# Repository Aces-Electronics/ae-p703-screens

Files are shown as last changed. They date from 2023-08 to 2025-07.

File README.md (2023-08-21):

<h1 align="center">
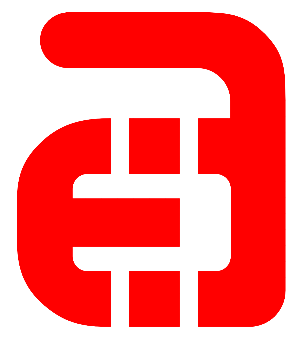
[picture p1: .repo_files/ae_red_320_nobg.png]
Ace's Electronics
    

  Ace's Electronics Pty Ltd  
  Touchscreen IO Control for P703 Rangers  
</h1>

# TOC:
1. <a href="#goals">Goals</a>
1. <a href="#current-states">Current States</a>
   - <a href="#reario-screen">RearIO: Screen</a>
   - <a href="#reario-battery">RearIO: Battery</a>
   - <a href="#reario-screen-and-battery-cradle">RearIO: Screen and Battery Cradle</a>
   - <a href="#reario-basic-pcb">RearIO: Basic PCB</a>
   - <a href="#reario-pro-pcb">RearIO: Pro PCB</a>
   - <a href="#frontio-screen">FrontIO: Screen</a>
1. <a href="#android-app">Android App</a>
1. <a href="#where-to-buy">Where to Buy</a>
1. <a href="#support">Support</a>
---
# Goals:
The goal of this project is to simplify the placement and connection of a secondary battery in a P703 Ranger, by:  
- Creating a touchscreen interface for stats and control, one in the cab and one in the tub  
- Minimise what's required to supply secondary battery power to things like fridges/freezers, lights, fans etc.
- Minimise what's required to turn things on and off  
- Display voltages/currents/power/load states and run flat times etc.
- Create a minimilist version that will require some externall hardware like an MPPT dual input controller etc.

# Current States:
## RearIO Screen
Screen has been sourced and basic prototype code has been written. Seems workable for now but more work is needed.

Screen (WT32-SC01 Plus):  
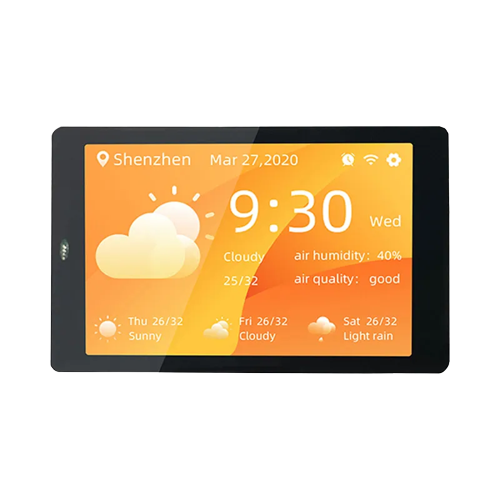
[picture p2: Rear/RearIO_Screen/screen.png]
WT32-SC01 Plus


Buy:
https://core-electronics.com.au/wt32-sc01-plus-esp32-development-board-with-35-inch-lcd-ips-display-touch-screen.html

Datasheet:
https://www.marutsu.co.jp/contents/shop/marutsu/datasheet/khe_WT32-SC01-PLUS.pdf

Basic GUI example: 
It's a WIP, but here's a taste:  
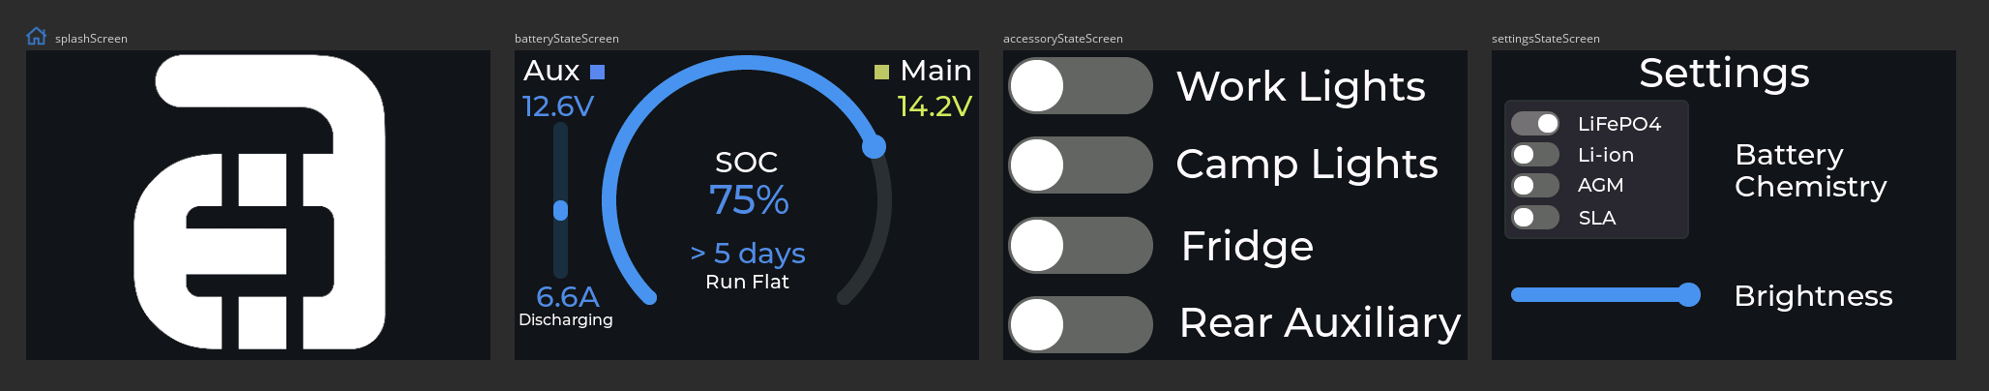
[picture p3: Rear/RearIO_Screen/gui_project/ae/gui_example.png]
GUI Example


## RearIO Battery
50Ah battery has een sourced and tested.  
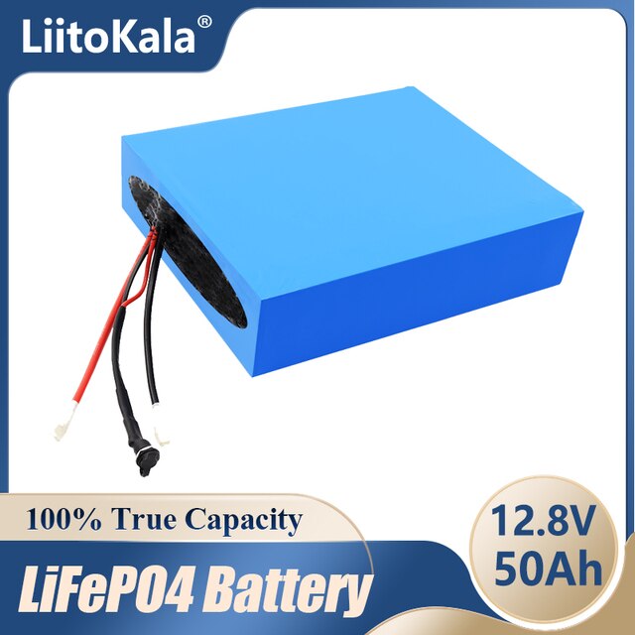
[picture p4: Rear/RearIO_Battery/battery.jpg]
LiFEPO4 Battery


## RearIO Screen and Battery Cradle
The screen and PCB mount is complete. It has cutouts for a marine grade 12v socket + an Anderson socket, and 2 x Anderson sockets.
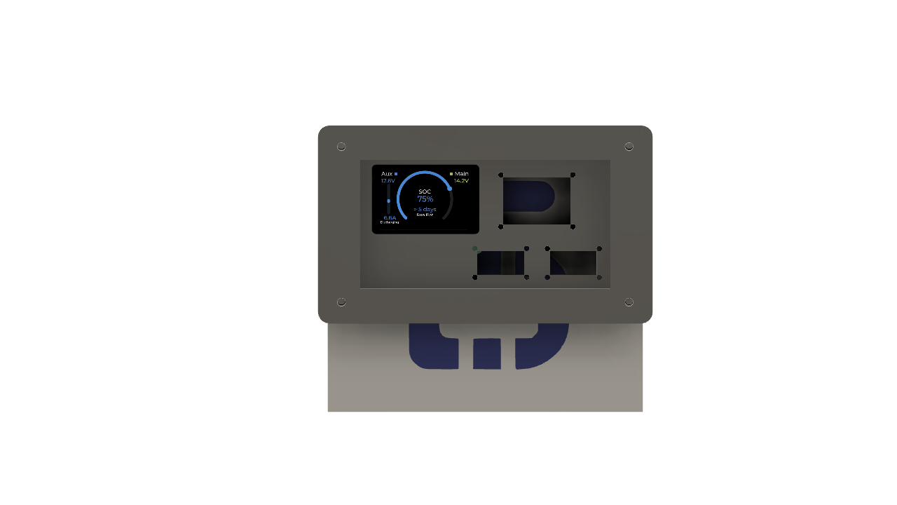
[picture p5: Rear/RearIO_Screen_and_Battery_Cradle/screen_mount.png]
Screen Mount Front

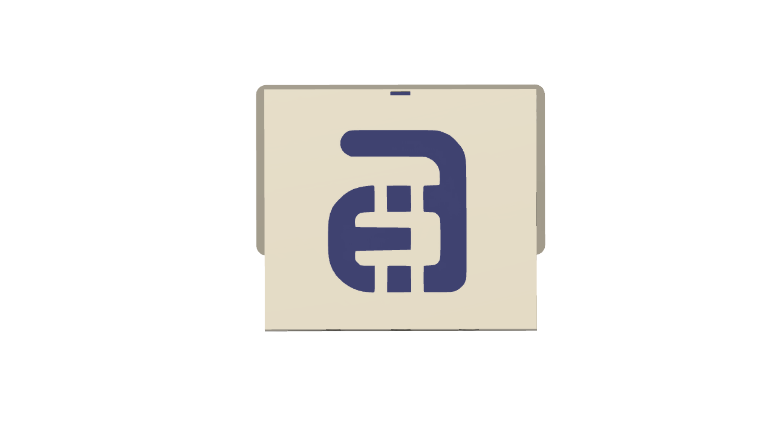
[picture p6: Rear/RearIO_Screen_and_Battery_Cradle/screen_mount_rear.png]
Screen Mount Rear

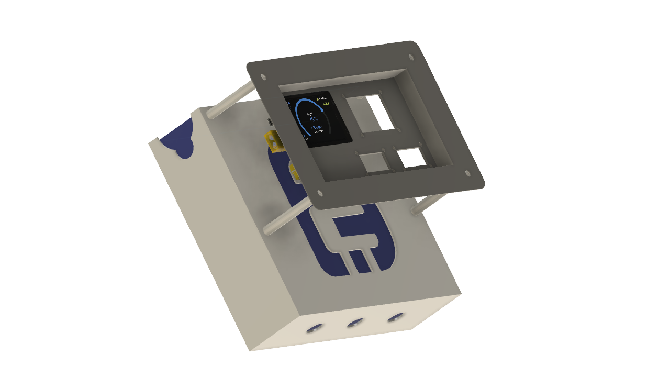
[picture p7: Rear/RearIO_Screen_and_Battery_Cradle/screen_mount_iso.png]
Screen Mount Iso


## RearIO Basic PCB
basic io screenshot The project is currently in the prototyping phase. The PCBs have been sent to JLCPCB and should be here, along with the components, in the next couple of weeks.  
Files: https://github.com/Aces-Electronics/ae-p703-screens/releases/tag/v0.1
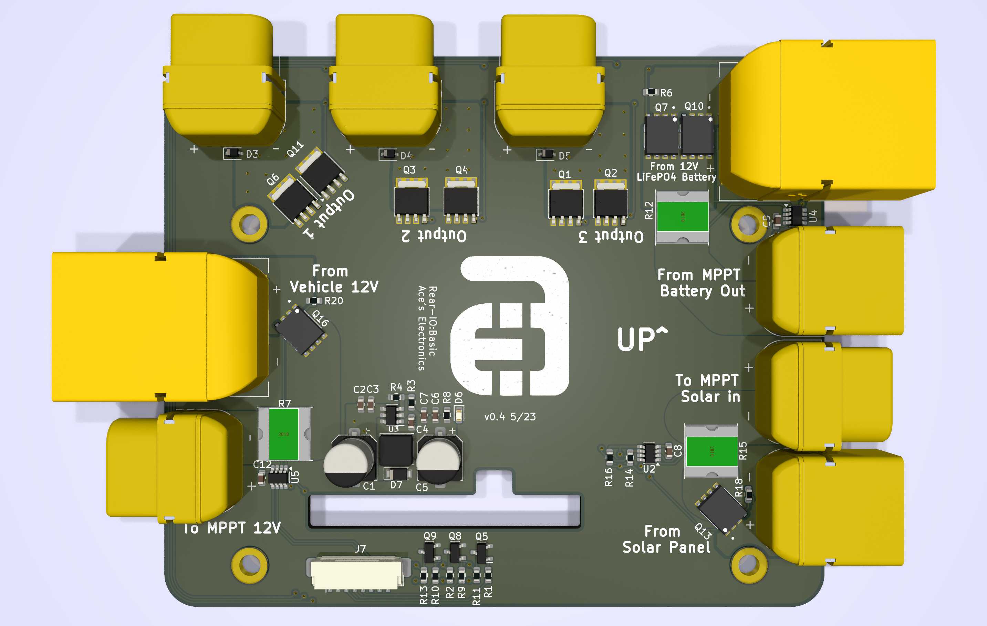
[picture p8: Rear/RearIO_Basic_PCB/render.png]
Basic PCB

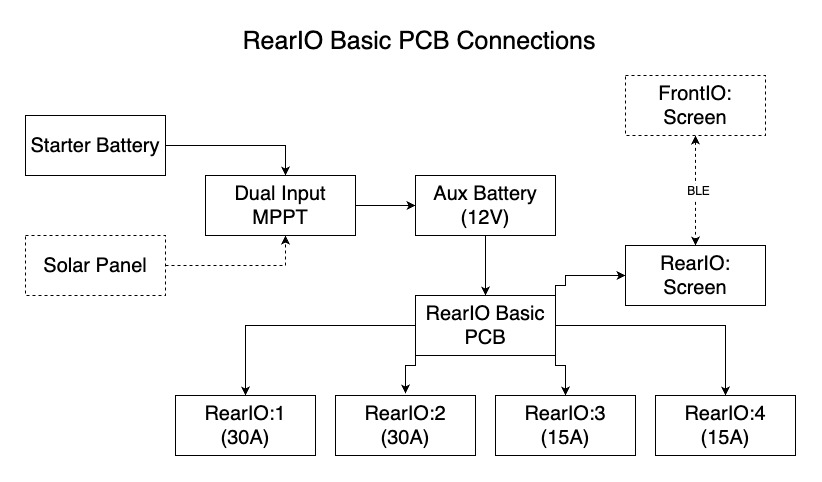
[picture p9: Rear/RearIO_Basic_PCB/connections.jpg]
Basic PCB Connections


## RearIO Pro PCB
The project is in the design stage, and is coming along as time allows.
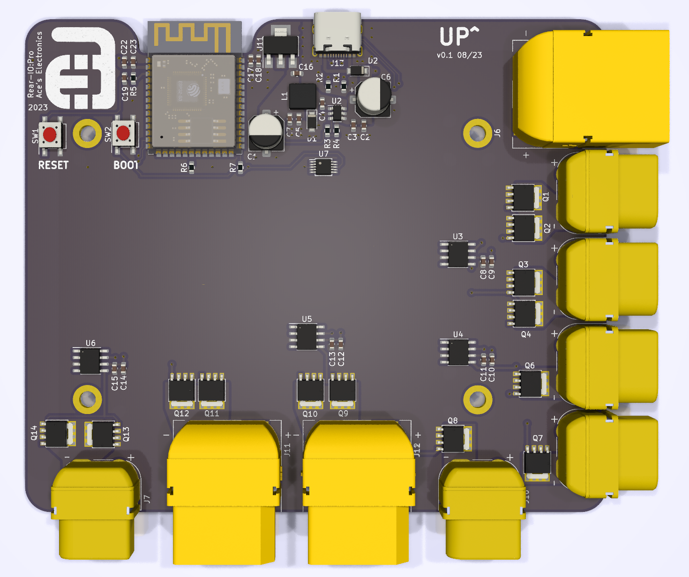
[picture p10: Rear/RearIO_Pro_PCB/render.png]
Pro PCB


## FrontIO Screen
Screen has been sourced. No testing has been done yet.
https://www.makerfabs.com/matouch-esp32-s3-parallel-tft-with-touch-1-9-inch.html  
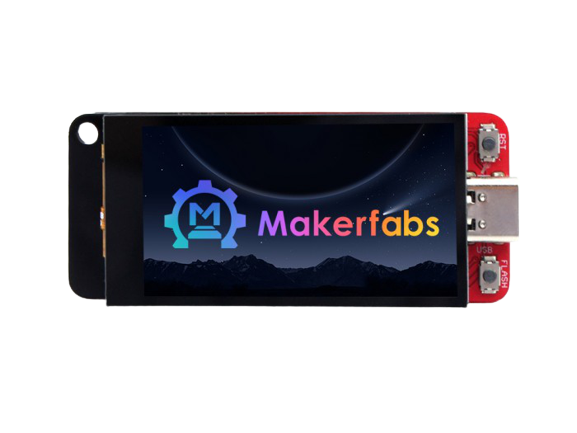
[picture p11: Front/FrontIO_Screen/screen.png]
MaTouch_ESP32-S3 Parallel TFT with Touch 1.9" ST7789V2


## Android App
Not yet started

# Where to Buy:
TBA

## Support:
Contact me direct via ace<@>aceselectronics.com.au, just make it look like a normal email address. (hiding from the bots ;) )

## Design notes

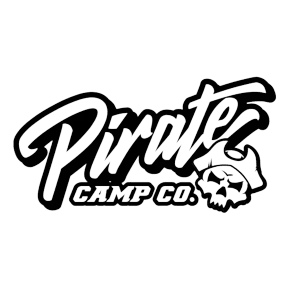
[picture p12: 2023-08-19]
Rear/RearIO_Screen_Basic_Software/gui_project/pcc/assets/pirate_camp_co_290.png

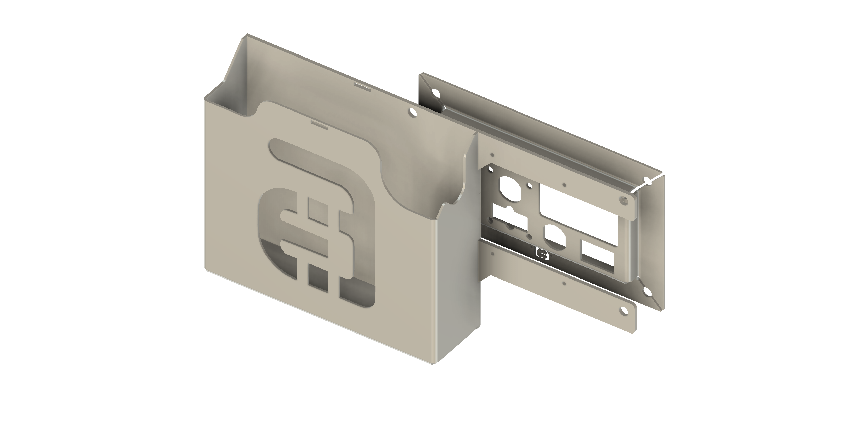
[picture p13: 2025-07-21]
Panel v64.png

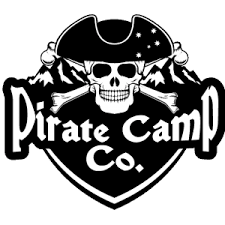
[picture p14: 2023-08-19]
Rear/RearIO_Screen_Pro_Software/gui_project/pcc/assets/images.png

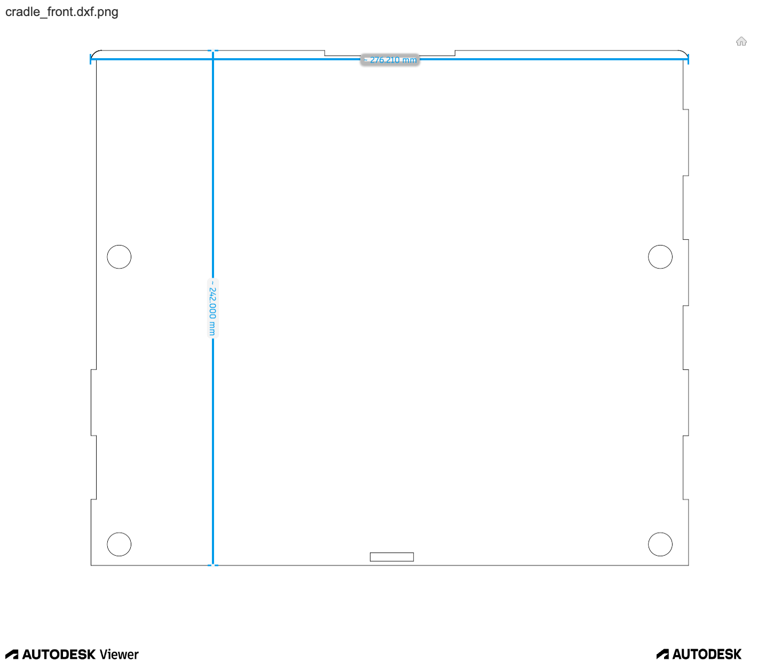
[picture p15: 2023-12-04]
Rear/RearIO_Screen_and_Battery_Cradle/DXF/folding/cradle_front.dxf.png

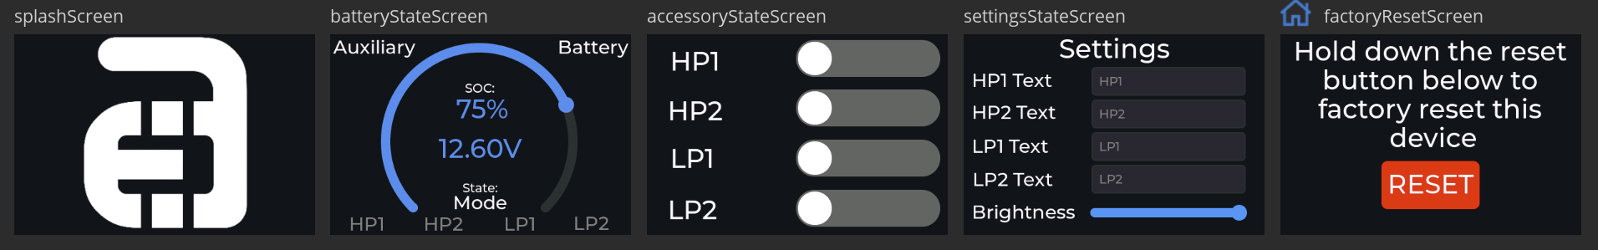
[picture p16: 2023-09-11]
Rear/RearIO_Screen_Pro_Software/gui_project/ae/gui_example.png

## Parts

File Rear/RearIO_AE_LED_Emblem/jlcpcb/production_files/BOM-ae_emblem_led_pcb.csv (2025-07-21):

Comment | Designator | Footprint | LCSC
330R | R1,R2,R3,R4,R5,R6 | R_0402_1005Metric | C12246
Conn_01x02_Socket | J1 | Hirose_DF13C_CL535-0402-2-51_1x02-1MP_P1.25mm_Vertical | C3029359
GREEN_LED | D1,D2,D3,D4,D5,D6 | LED_0402_1005Metric | C434449

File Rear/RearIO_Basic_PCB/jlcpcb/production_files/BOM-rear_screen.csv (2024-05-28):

Comment | Designator | Footprint | LCSC
82k | R3 | R_0603_1608Metric | C103831
1k | R1,R10,R9 | R_0603_1608Metric | C21190
2k | R14,R16 | R_0603_1608Metric | C22975
5.1k | R8 | R_0603_1608Metric | C23186
10uH | L1 | L_Chilisin_BMRA00040415 | C2847473
1N5819WS | D3,D4,D5 | D_SOD-323 | C2927280
Conn_01x02_Pin | J10,J6 | AMASS_XT90PW-M | C3040689
100nF | C12,C2,C3,C4,C6,C7,C8,C9 | C_0603_1608Metric | C30926
220uF | C1 | CP_Elec_6.3x7.7 | C340768
AON6411 | Q10,Q13,Q16,Q7 | PowerDI5060-8 | C397981
16k | R11,R13,R18,R2,R20,R4,R6 | R_0603_1608Metric | C4210
Conn_01x02_Pin | J1,J11,J3,J4,J5 | AMASS_XT60PW-F_1x02_P7.20mm_Horizontal | C428722
10mR | R12,R15,R7 | 2728R_C500749 | C500749
AOZ1280CI | U3 | SOT-23-6 | C5123971
NTMFS4C03N-HXY | Q1,Q11,Q2,Q3,Q4,Q6 | LFPAK56 | C5148663
Conn_01x08_Socket | J7 | BOOMELE-Boom-Precision-Elec-C53040_C53040 | C53040
INA236AIDDFR_C5443912 | U2,U4,U5 | SOT-23-8 | C5443912
LED_Small | D6 | LED_0603_1608Metric | C84264
MMBT3904 | Q5,Q8,Q9 | SOT-23 | C8512
PMEG6020ER | D7 | Nexperia_CFP3_SOD-123W | C98663
Conn_01x02_Pin | J2,J9 | AMASS_XT60PW-M_1x02_P7.20mm_Horizontal | C98732
22uF | C5 | CP_Elec_6.3x5.4 | C98744

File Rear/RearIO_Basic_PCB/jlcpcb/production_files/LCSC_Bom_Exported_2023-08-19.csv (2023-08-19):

LCSC Part Number | Quoted Manufacturer | Quoted LCSC Part Number | Quoted Manufacturer Part Number | Quantity | Unit Price | Order Price | Quantity Available | Min\Mult Order Qty | RoHS | Part Match Confidence
C103831 | RALEC | C103831 | RTT038202FTP | 100 | 0.0028 | 0.28 | 99700 | 100\100 | yes | 100%
C23186 | UNI-ROYAL(Uniroyal Elec) | C23186 | 0603WAF5101T5E | 100 | 0.001 | 0.10 | 1548200 | 100\100 | yes | 100%
C2685358 | COSINE | C2685358 | COS4427SR | 10 | 0.3882 | 3.88 | 20107 | 1\1 | yes | 100%
C2847473 | KOHERelec | C2847473 | MDA4020-100M | 5 | 0.7701 | 3.85 | 2076 | 1\1 | yes | 100%
C2927280 | JSMSEMI | C2927280 | 1N5819WS S4 | 25 | 0.0085 | 0.20 | 558490 | 5\5 | yes | 100%
C2988369 | G-Switch | C2988369 | GT-USB-7010ASV | 5 | 0.0787 | 0.35 | 39365 | 5\5 | yes | 100%
C3040689 | Changzhou Amass Elec | C3040689 | XT90PW-M.G.Y | 5 | 0.63 | 3.02 | 725 | 1\1 | yes | 100%
C30926 | FH (Guangdong Fenghua Advanced Tech) | C30926 | 0603B104K500NT | 100 | 0.0023 | 0.23 | 40547100 | 100\100 | yes | 100%
C4210 | UNI-ROYAL(Uniroyal Elec) | C4210 | 0603WAF1602T5E | 100 | 0.001 | 0.10 | 322600 | 100\100 | yes | 100%
C5123971 | Legend-Si | C5123971 | LGS5145 | 5 | 0.1169 | 0.50 | 51050 | 5\5 | yes | 100%
C5148663 | HXY MOSFET | C5148663 | NTMFS4C03N-HXY | 30 | 0.2801 | 8.40 | 469 | 1\1 | yes | 100%
C53040 | BOOMELE(Boom Precision Elec) | C53040 | C53040 | 19 | 0.0781 | 1.48 | 6650 | 19\19 | yes | 100%
C98663 | Nexperia | C98663 | PMEG6020ER,115 | 5 | 0.1329 | 0.66 | 10075 | 5\5 | yes | 100%
C98744 | ST(Semtech) | C98744 | CS1H220M-CRE54 | 10 | 0.0274 | 0.27 | 103030 | 10\10 | yes | 100%
C99836 | ROQANG | C99836 | RVE1C221M0607 | 10 | 0.0446 | 0.40 | 310710 | 10\10 | yes | 100%

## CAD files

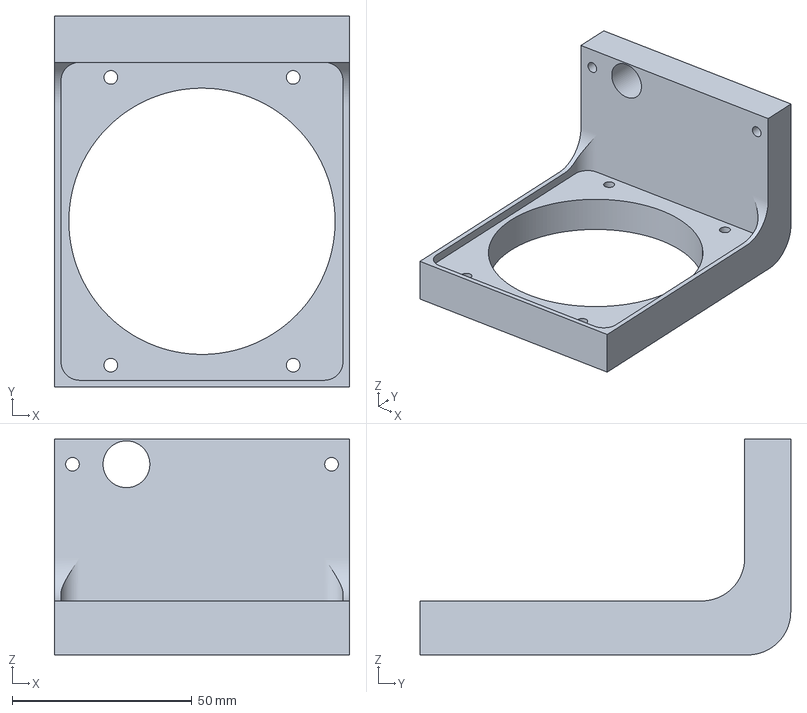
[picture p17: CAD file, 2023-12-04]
Engine_Bay/battery_isolator_bracket.3mf
82.0 x 103.0 x 60.0 mm

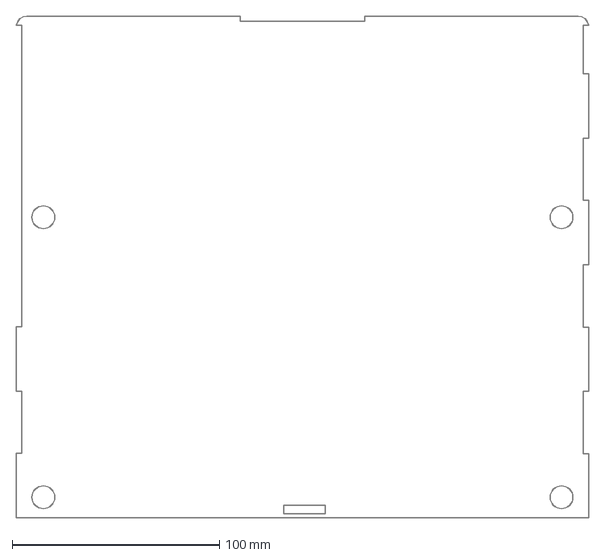
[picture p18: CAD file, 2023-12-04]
Rear/RearIO_Screen_and_Battery_Cradle/DXF/folding/cradle_front.dxf
276.0 x 242.0 mm

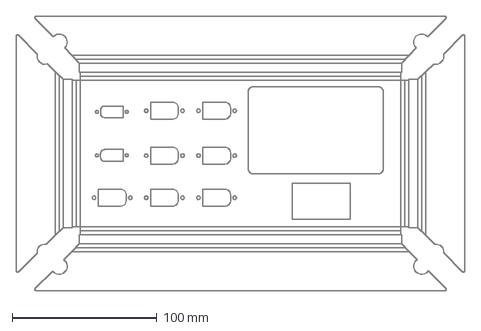
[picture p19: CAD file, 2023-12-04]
Rear/RearIO_Screen_and_Battery_Cradle/DXF/folding/panel.dxf
309.6 x 189.6 mm

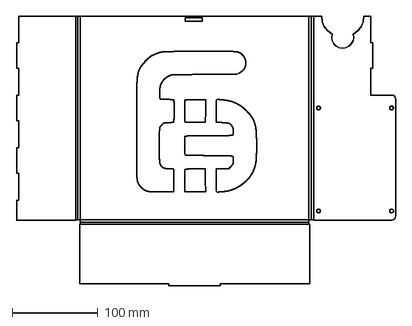
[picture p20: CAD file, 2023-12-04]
Rear/RearIO_Screen_and_Battery_Cradle/DXF/folding/cradle_rear.dxf
441.9 x 314.3 mm

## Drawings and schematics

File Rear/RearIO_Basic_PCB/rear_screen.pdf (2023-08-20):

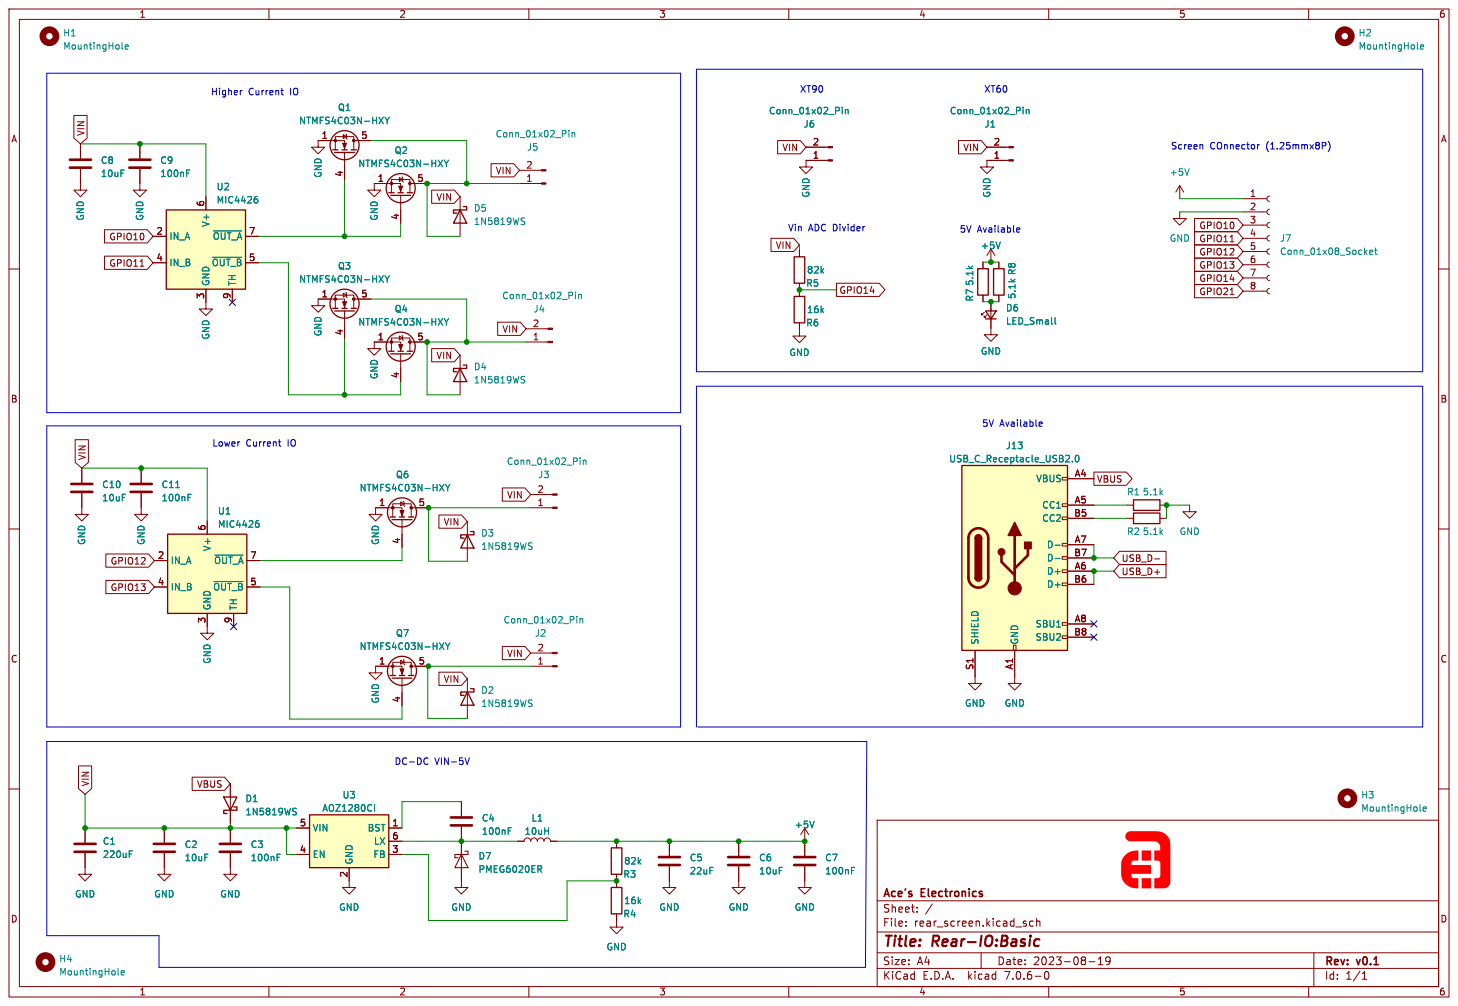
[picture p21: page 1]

6 ~{OUT_A}7 U2 MIC4426 GND GND GND GND

Id: 1/1 Title: Rear-IO:Basic

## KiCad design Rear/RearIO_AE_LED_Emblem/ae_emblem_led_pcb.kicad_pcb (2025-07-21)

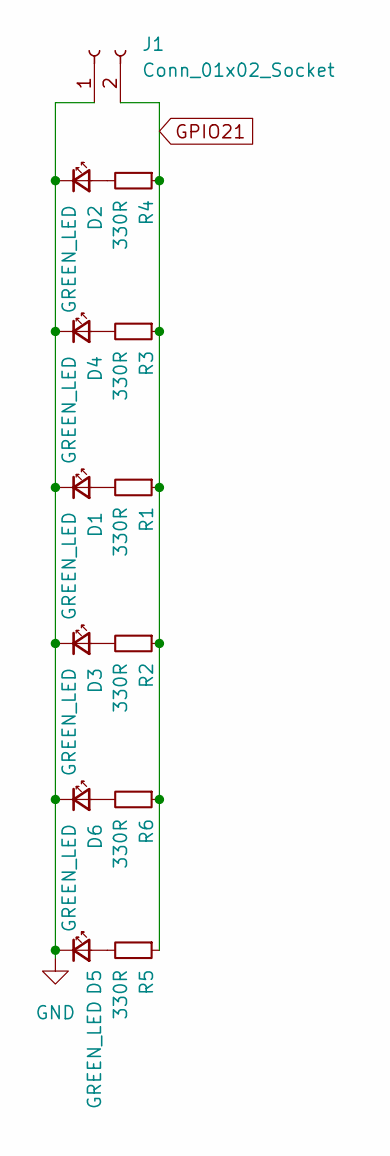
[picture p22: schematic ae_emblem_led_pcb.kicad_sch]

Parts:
D1, D2, D3, D4, D5, D6: GREEN_LED; LED_0402_1005Metric; lcsc C434449
J1: Conn_01x02_Socket; Hirose_DF13C_CL535-0402-2-51_1x02-1MP_P1.25mm_Vertical; lcsc C3029359
R1, R2, R3, R4, R5, R6: 330R; R_0402_1005Metric; lcsc C12246

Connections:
GND: D1.1 (K), D2.1 (K), D3.1 (K), D4.1 (K), D5.1 (K), D6.1 (K), J1.1
GPIO21: J1.2, R1.1, R2.1, R3.1, R4.1, R5.1, R6.1
unnamed: D1.2 (A), R1.2
unnamed: D2.2 (A), R4.2
unnamed: D3.2 (A), R2.2
unnamed: D4.2 (A), R3.2
unnamed: D5.2 (A), R5.2
unnamed: D6.2 (A), R6.2

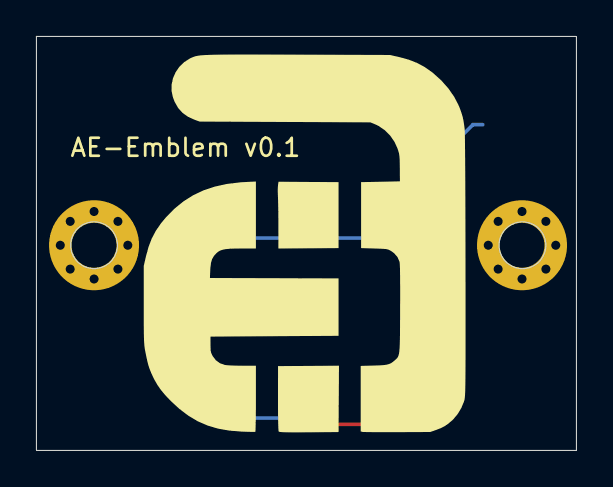
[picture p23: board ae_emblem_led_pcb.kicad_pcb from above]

Board: 2 copper layers, 30.0 x 23.0 mm, 13 parts (1 on the bottom side), 8 nets.

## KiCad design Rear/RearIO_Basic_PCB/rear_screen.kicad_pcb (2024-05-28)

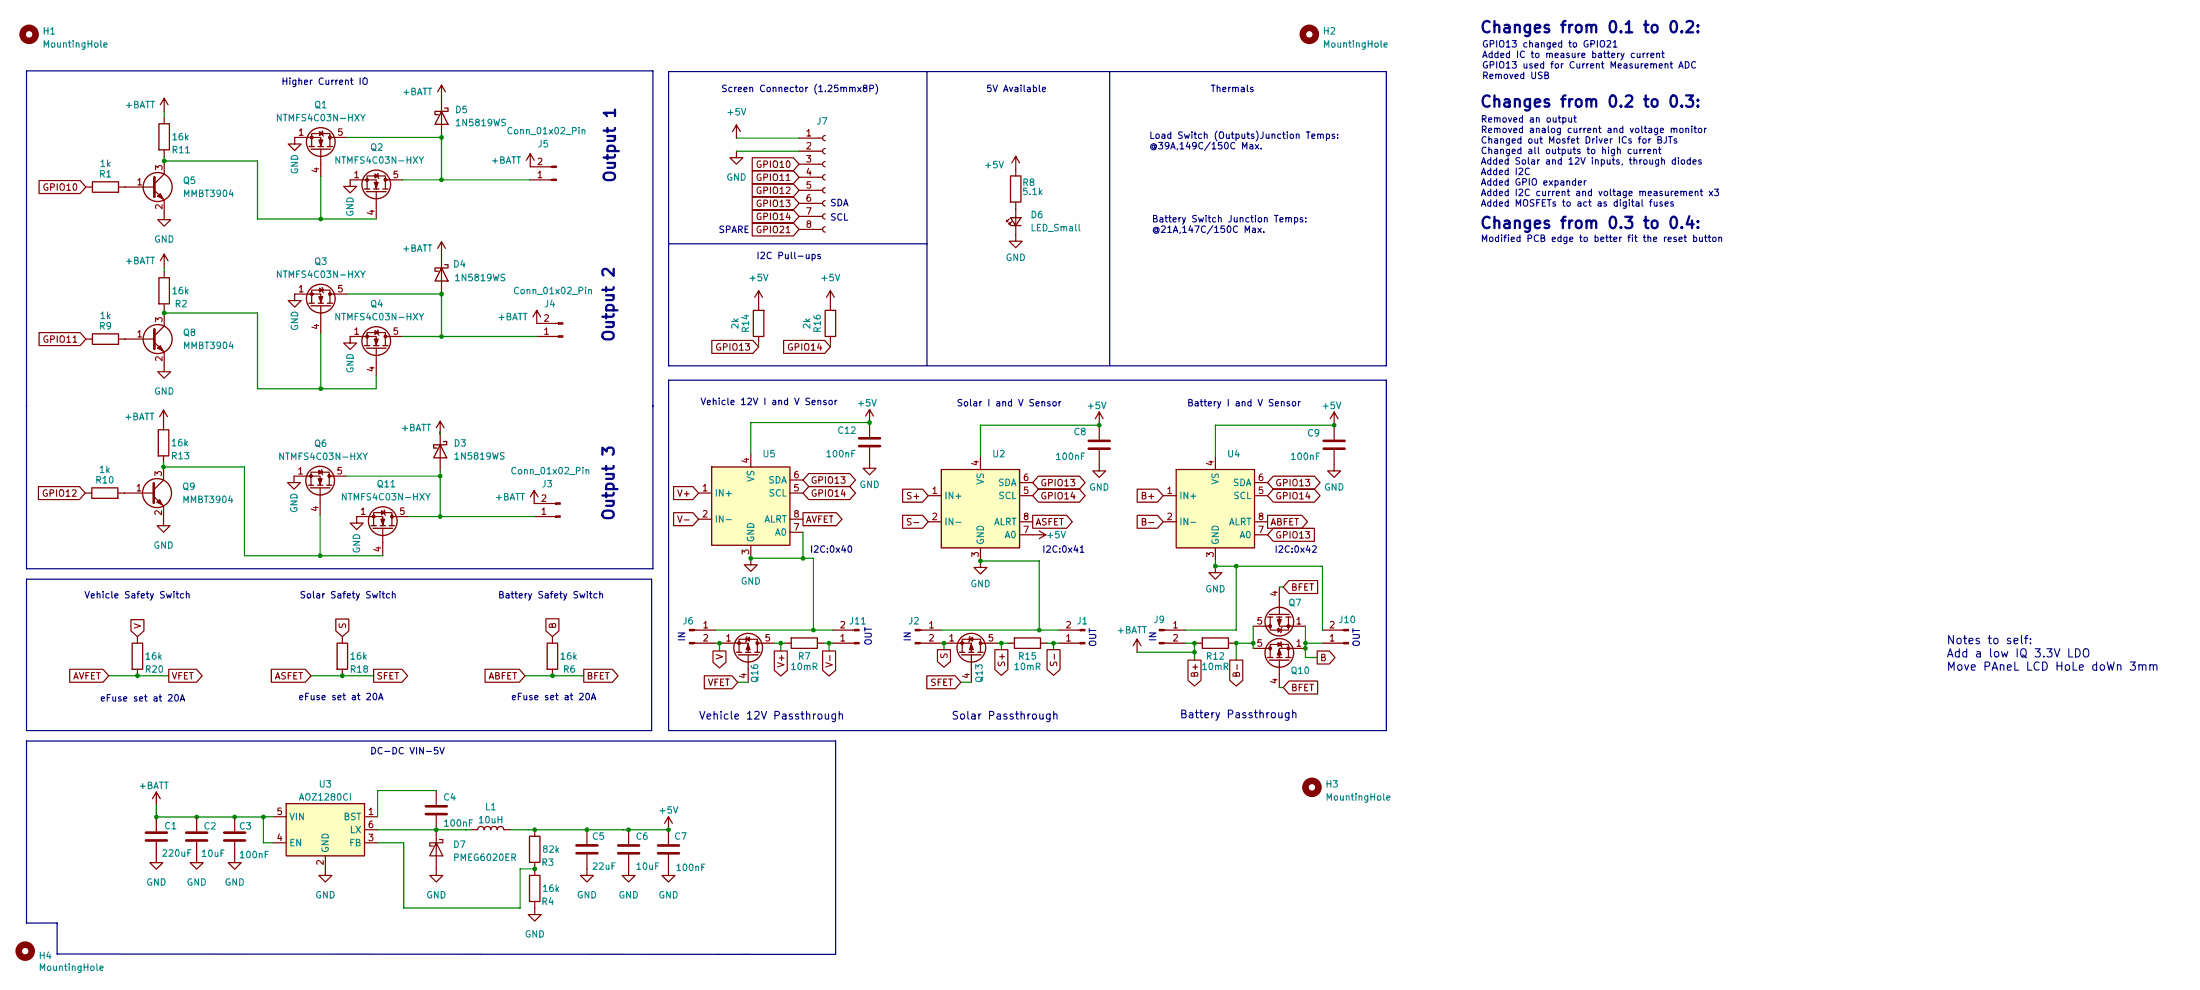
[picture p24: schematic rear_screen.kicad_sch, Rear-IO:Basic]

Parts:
C1: 220uF; CP_Elec_6.3x7.7; lcsc C340768
C2, C6: 10uF; C_0603_1608Metric; lcsc C30926
C3, C4, C7, C8, C9, C12: 100nF; C_0603_1608Metric; lcsc C30926
C5: 22uF; CP_Elec_6.3x5.4; lcsc C98744
D3, D4, D5: 1N5819WS; D_SOD-323; lcsc C2927280
D6: LED_Small; LED_0603_1608Metric; lcsc C84264
D7: PMEG6020ER; Nexperia_CFP3_SOD-123W; lcsc C98663
H1, H2, H3, H4: MountingHole; MountingHole_3.2mm_M3_DIN965_Pad
J1, J3, J4, J5, J11: Conn_01x02_Pin; AMASS_XT60PW-F_1x02_P7.20mm_Horizontal; lcsc C428722
J2, J9: Conn_01x02_Pin; AMASS_XT60PW-M_1x02_P7.20mm_Horizontal; lcsc C98732
J6, J10: Conn_01x02_Pin; AMASS_XT90PW-M; lcsc C3040689
J7: Conn_01x08_Socket; BOOMELE-Boom-Precision-Elec-C53040_C53040; lcsc C53040
L1: 10uH; L_Chilisin_BMRA00040415; lcsc C2847473
Q1, Q2, Q3, Q4, Q6, Q11: NTMFS4C03N-HXY; LFPAK56; lcsc C5148663
Q5, Q8, Q9: MMBT3904; SOT-23; lcsc C8512
Q7, Q10, Q13, Q16: AON6411; PowerDI5060-8; lcsc C397981
R1, R9, R10: 1k; R_0603_1608Metric; lcsc C21190
R2, R4, R6, R11, R13, R18, R20: 16k; R_0603_1608Metric; lcsc C4210
R3: 82k; R_0603_1608Metric; lcsc C103831
R7, R12, R15: 10mR; 2728R_C500749; lcsc C500749
R8: 5.1k; R_0603_1608Metric; lcsc C23186
R14, R16: 2k; R_0603_1608Metric; lcsc C22975
U2, U4, U5: INA236AIDDFR_C5443912; SOT-23-8; lcsc C5443912
U3: AOZ1280CI; SOT-23-6; lcsc C5123971

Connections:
+5V: C5.1, C6.1, C7.1, C8.1, C9.1, C12.1, J7.1, L1.2, R3.1, R8.1, R14.2, R16.2, U2.4 (VS), U2.7 (A0), U4.4 (VS), U5.4 (VS)
ABFET: Q7.4 (G), Q10.4 (G), R6.2, U4.8 (ALRT)
ASFET: Q13.4 (G), R18.2, U2.8 (ALRT)
AVFET: Q16.4 (G), R20.2, U5.8 (ALRT)
B: J10.1, Q7.1 (S), Q7.2 (S), Q7.3 (S), Q10.1 (S), Q10.2 (S), Q10.3 (S), R6.1
B+: C1.1, C2.1, C3.1, D3.1 (K), D4.1 (K), D5.1 (K), J3.2, J4.2, J5.2, J9.2, R2.1, R11.1, R12.2, R13.1, U3.4 (EN), U3.5 (VIN), U4.1 (IN+)
B-: Q7.5 (D), Q10.5 (D), R12.1, U4.2 (IN-)
GND: C1.2, C2.2, C3.2, C5.2, C6.2, C7.2, C8.2, C9.2, C12.2, D6.1 (K), D7.2 (A), J1.2, J2.1, J6.1, J7.2, J9.1, J10.2, J11.2, Q1.1 (S), Q1.2 (S), Q1.3 (S), Q2.1 (S), Q2.2 (S), Q2.3 (S), Q3.1 (S), Q3.2 (S), Q3.3 (S), Q4.1 (S), Q4.2 (S), Q4.3 (S), Q5.2 (E), Q6.1 (S), Q6.2 (S), Q6.3 (S), Q8.2 (E), Q9.2 (E), Q11.1 (S), Q11.2 (S), Q11.3 (S), R4.2, U2.3 (GND), U3.2 (GND), U4.3 (GND), U5.3 (GND), U5.7 (A0)
GPIO10: J7.3, R1.1
GPIO11: J7.4, R9.1
GPIO12: J7.5, R10.1
GPIO13: J7.6, R14.1, U2.6 (SDA), U4.6 (SDA), U4.7 (A0), U5.6 (SDA)
GPIO14: J7.7, R16.1, U2.5 (SCL), U4.5 (SCL), U5.5 (SCL)
GPIO21: J7.8
unnamed: D3.2 (A), J3.1, Q6.5 (D), Q11.5 (D)
unnamed: D4.2 (A), J4.1, Q3.5 (D), Q4.5 (D)
unnamed: D5.2 (A), J5.1, Q1.5 (D), Q2.5 (D)
unnamed: D6.2 (A), R8.2
unnamed: C4.2, D7.1 (K), L1.1, U3.6 (LX)
unnamed: Q1.4 (G), Q2.4 (G), Q5.3 (C), R11.2
unnamed: Q3.4 (G), Q4.4 (G), Q8.3 (C), R2.2
unnamed: Q5.1 (B), R1.2
unnamed: Q8.1 (B), R9.2
unnamed: Q9.1 (B), R10.2
unnamed: Q6.4 (G), Q9.3 (C), Q11.4 (G), R13.2
unnamed: C4.1, U3.1 (BST)
unnamed: R3.2, R4.1, U3.3 (FB)
S: J2.2, Q13.1 (S), Q13.2 (S), Q13.3 (S), R18.1
S+: Q13.5 (D), R15.2, U2.1 (IN+)
S-: J1.1, R15.1, U2.2 (IN-)
V: J6.2, Q16.1 (S), Q16.2 (S), Q16.3 (S), R20.1
V+: Q16.5 (D), R7.2, U5.1 (IN+)
V-: J11.1, R7.1, U5.2 (IN-)

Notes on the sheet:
Higher Current IO
I2C:0x40
Changes from 0.3 to 0.4:
Changes from 0.2 to 0.3:
Vehicle Safety Switch
I2C:0x41
Battery Passthrough
Load Switch (Outputs)Junction Temps: @39A,149C/150C Max.
OUT
eFuse set at 20A
Output 2
Battery Switch Junction Temps: @21A,147C/150C Max.
DC-DC VIN-5V
Output 1
Vehicle 12V Passthrough
Screen Connector (1.25mmx8P)
Vehicle 12V I and V Sensor
Output 3
Solar Safety Switch
Changes from 0.1 to 0.2:
I2C:0x42
Battery I and V Sensor
Solar I and V Sensor
Battery Safety Switch
Removed an output Removed analog current and voltage monitor Changed out Mosfet Driver ICs for BJTs Changed all outputs to high current Added Solar and 12V inputs, through diodes Added I2C Added GPIO expander Added I2C current and voltage measurement x3 Added MOSFETs to act as digital fuses
I2C Pull-ups
Modified PCB edge to better fit the reset button
SDA
Thermals
SPARE
5V Available
Notes to self: Add a low IQ 3.3V LDO Move PAneL LCD HoLe doWn 3mm
Solar Passthrough
SCL
GPIO13 changed to GPIO21 Added IC to measure battery current GPIO13 used for Current Measurement ADC Removed USB

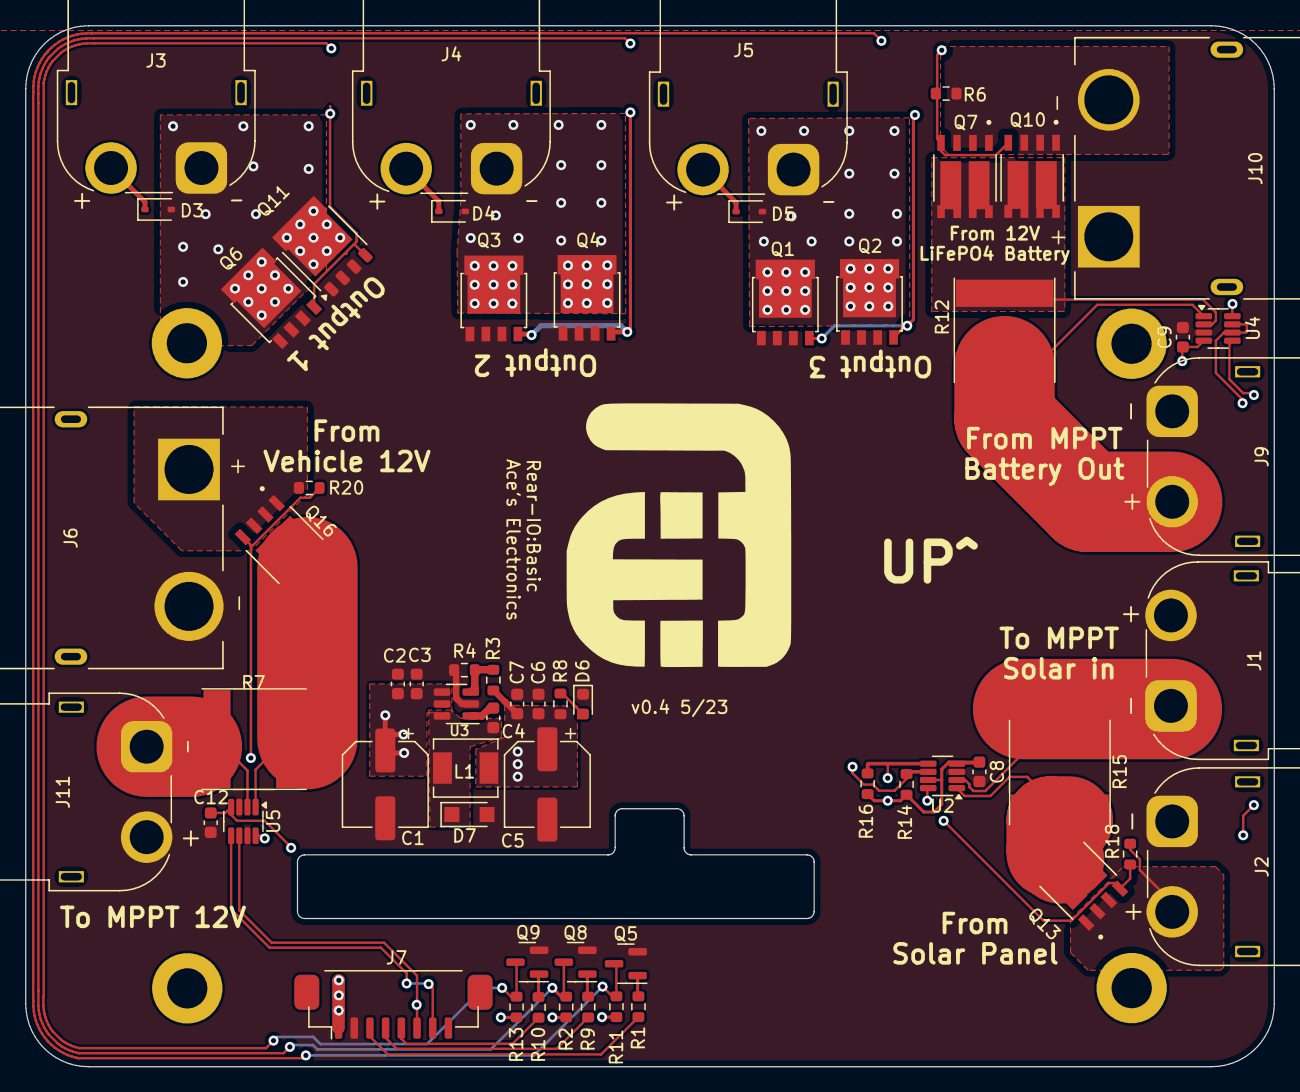
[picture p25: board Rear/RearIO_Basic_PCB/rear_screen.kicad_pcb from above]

Board: 4 copper layers, 99.4 x 82.9 mm, 64 parts (0 on the bottom side), 32 nets.

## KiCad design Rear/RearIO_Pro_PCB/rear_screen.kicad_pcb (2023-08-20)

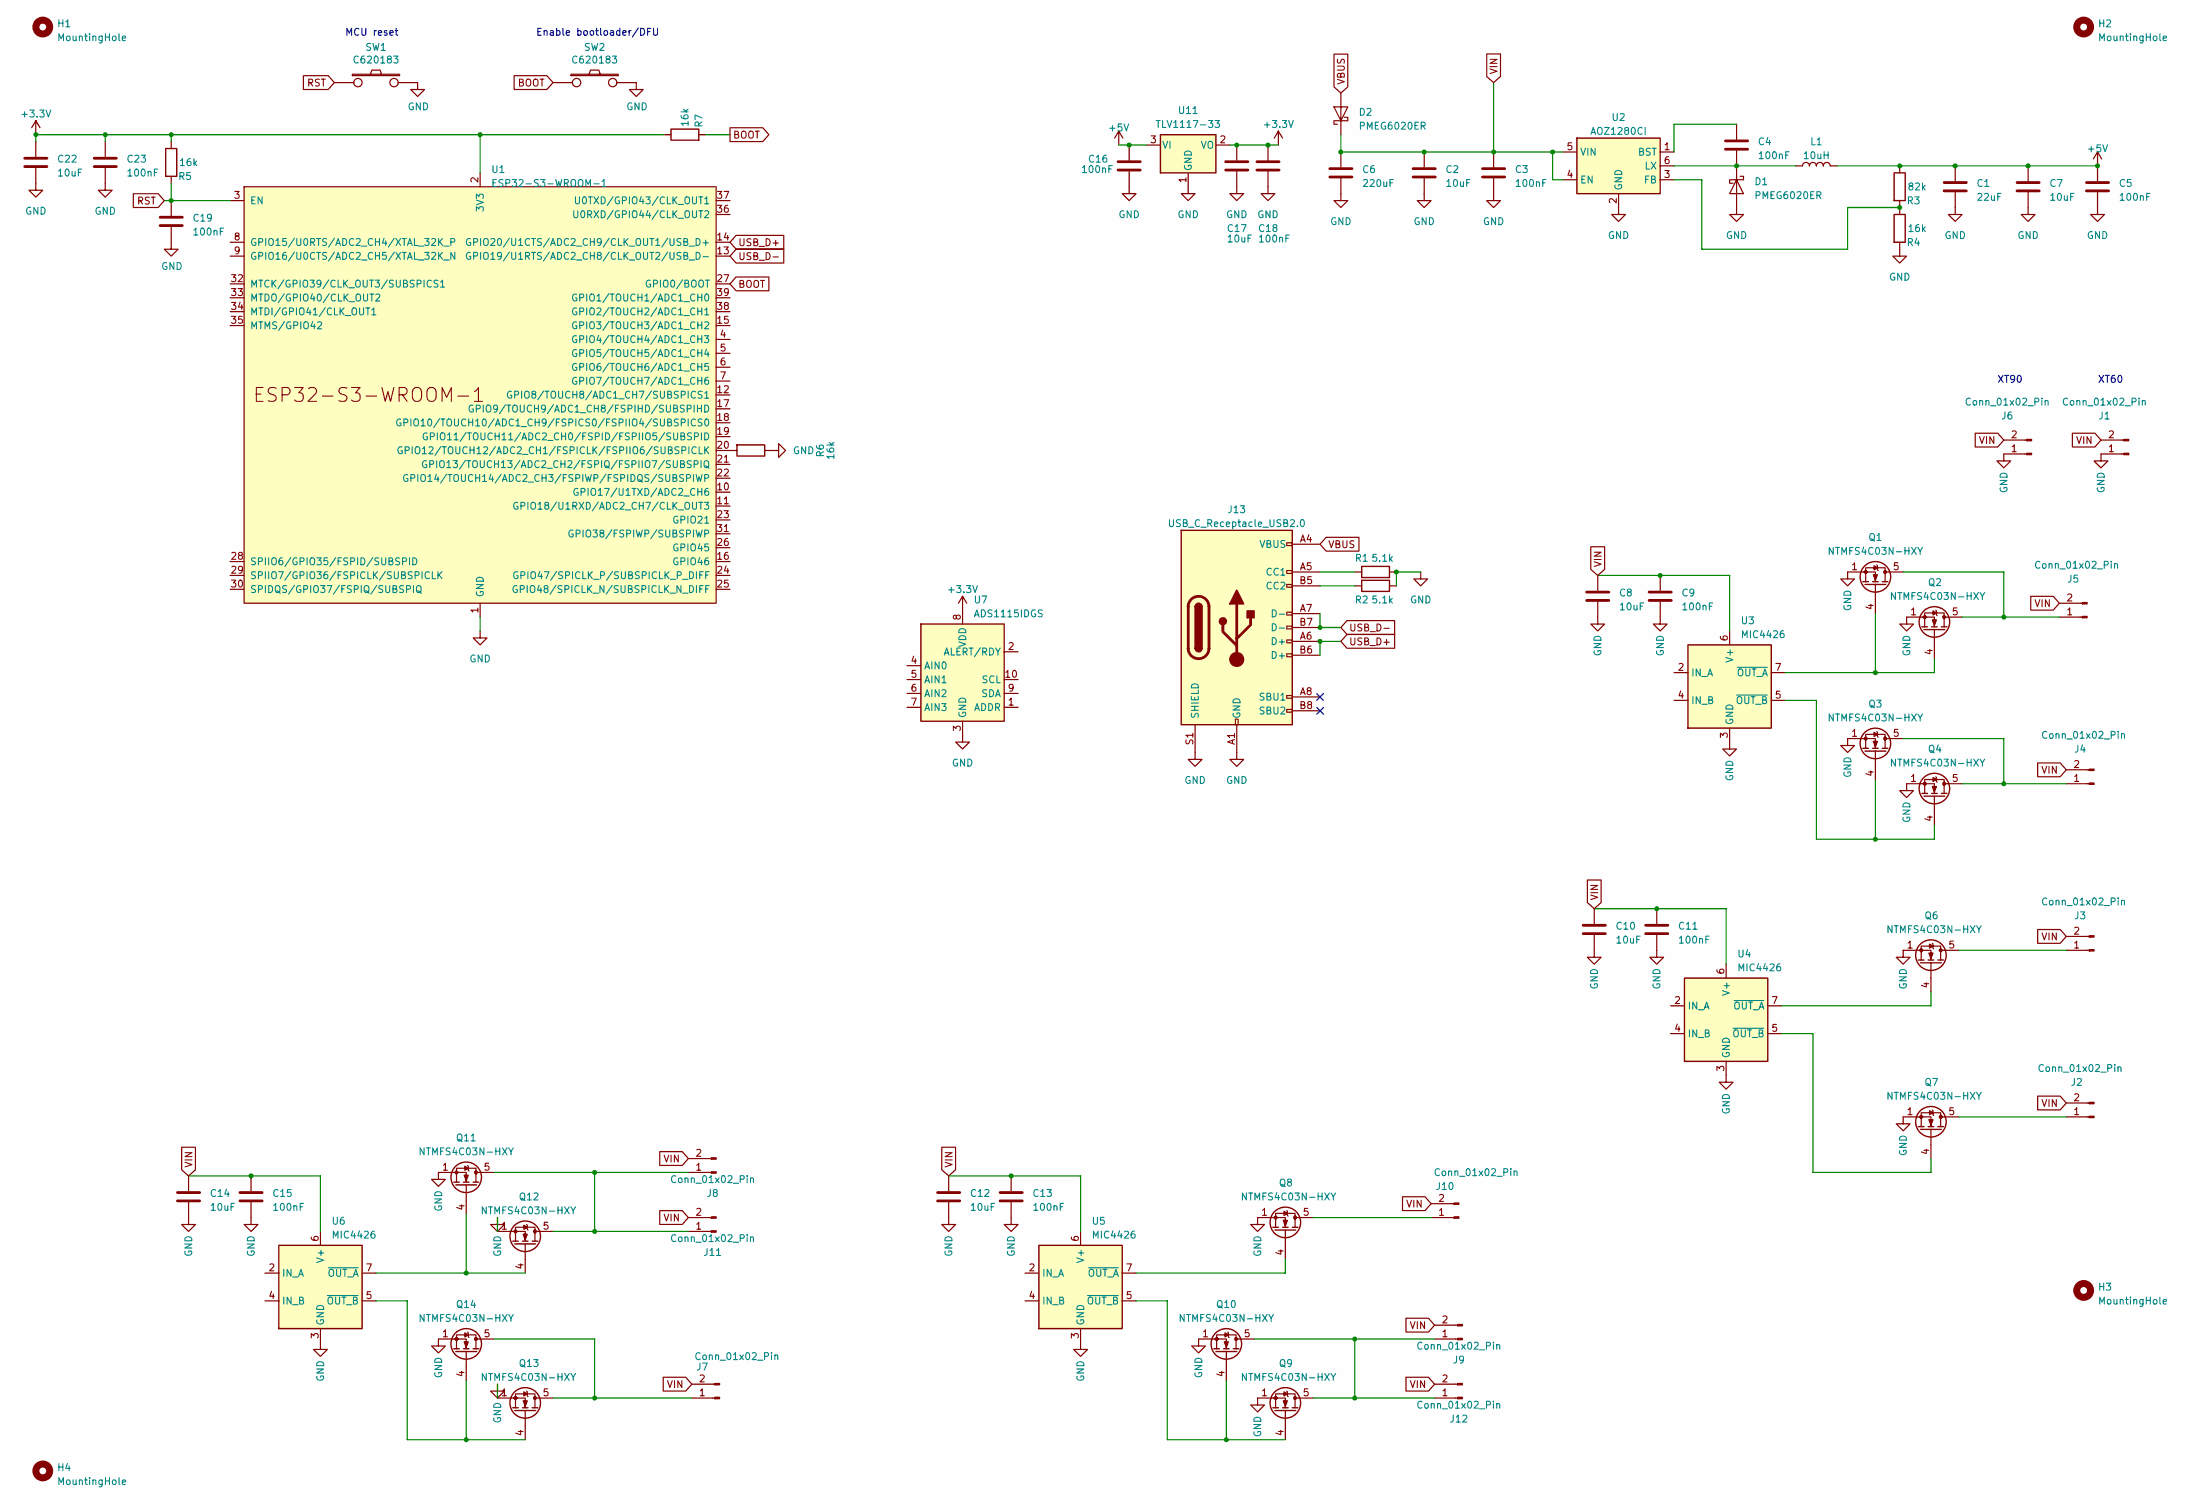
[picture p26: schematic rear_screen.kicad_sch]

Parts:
C1: 22uF; CP_Elec_6.3x5.4; lcsc C98744
C2, C7, C8, C10, C12, C14, C17, C22: 10uF; C_0603_1608Metric; lcsc C30926
C3, C4, C5, C9, C11, C13, C15, C16, C18, C19, C23: 100nF; C_0603_1608Metric; lcsc C30926
C6: 220uF; CP_Elec_6.3x7.7; lcsc C99836
D1, D2: PMEG6020ER; Nexperia_CFP3_SOD-123W; lcsc C98663
H1, H2, H3, H4: MountingHole; MountingHole_3.2mm_M3_DIN965_Pad
J1: Conn_01x02_Pin; AMASS_XT60PW-M_1x02_P7.20mm_Horizontal; lcsc C98732
J2, J3, J4, J5, J7, J8, J9, J10: Conn_01x02_Pin; AMASS_XT60PW-F_1x02_P7.20mm_Horizontal; lcsc C428722
J6: Conn_01x02_Pin; AMASS_XT90PW-M; lcsc C3040689
J11, J12: Conn_01x02_Pin; AMASS_XT90PW-F; lcsc C3040690
J13: USB_C_Receptacle_USB2.0; USB_C_Receptacle_G-Switch_GT-USB-7010ASV; lcsc C2988369
L1: 10uH; L_Chilisin_BMRA00040415; lcsc C2847473
Q1, Q2, Q3, Q4, Q6, Q7, Q8, Q9, Q10, Q11, Q12, Q13, Q14: NTMFS4C03N-HXY; LFPAK56; lcsc C5148663
R1, R2: 5.1k; R_0603_1608Metric; lcsc C23186
R3: 82k; R_0603_1608Metric; lcsc C103831
R4, R5, R6, R7: 16k; R_0603_1608Metric; lcsc C4210
SW1: C620183; TS4550TP; lcsc C620183
SW2: C620183; TS4550TP; lcsc_part_number C620183
U1: ESP32-S3-WROOM-1
U2: AOZ1280CI; SOT-23-6; lcsc C5123971
U3, U4, U5, U6: MIC4426; HSOP-8-1EP_3.9x4.9mm_P1.27mm_EP2.41x3.1mm_ThermalVias; lcsc C2685358
U7: ADS1115IDGS; TSSOP-10_3x3mm_P0.5mm
U11: TLV1117-33; SOT-223; lcsc C15578

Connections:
+3.3V: C17.1, C18.1, C22.1, C23.1, R5.1, R7.1, U1.2 (3V3), U7.8 (VDD), U11.2 (VO)
+5V: C1.1, C5.1, C7.1, C16.1, L1.2, R3.1, U11.3 (VI)
BOOT: R7.2, SW2.1, U1.27 (GPIO0/BOOT)
GND: C1.2, C2.2, C3.2, C5.2, C6.2, C7.2, C8.2, C9.2, C10.2, C11.2, C12.2, C13.2, C14.2, C15.2, C16.2, C17.2, C18.2, C19.2, C22.2, C23.2, D1.2 (A), J1.1, J6.1, J13.A1 (GND), J13.A12 (GND), J13.B1 (GND), J13.B12 (GND), J13.S1 (SHIELD), Q1.1 (S), Q1.2 (S), Q1.3 (S), Q2.1 (S), Q2.2 (S), Q2.3 (S), Q3.1 (S), Q3.2 (S), Q3.3 (S), Q4.1 (S), Q4.2 (S), Q4.3 (S), Q6.1 (S), Q6.2 (S), Q6.3 (S), Q7.1 (S), Q7.2 (S), Q7.3 (S), Q8.1 (S), Q8.2 (S), Q8.3 (S), Q9.1 (S), Q9.2 (S), Q9.3 (S), Q10.1 (S), Q10.2 (S), Q10.3 (S), Q11.1 (S), Q11.2 (S), Q11.3 (S), Q12.1 (S), Q12.2 (S), Q12.3 (S), Q13.1 (S), Q13.2 (S), Q13.3 (S), Q14.1 (S), Q14.2 (S), Q14.3 (S), R1.2, R2.1, R4.2, R6.1, SW1.2, SW2.2, U1.1 (GND), U1.40 (GND), U1.41 (GND), U2.2 (GND), U3.3 (GND), U4.3 (GND), U5.3 (GND), U6.3 (GND), U7.3 (GND), U11.1 (GND)
unnamed: C4.2, D1.1 (K), L1.1, U2.6 (LX)
unnamed: J2.1, Q7.5 (D)
unnamed: J3.1, Q6.5 (D)
unnamed: J4.1, Q3.5 (D), Q4.5 (D)
unnamed: J5.1, Q1.5 (D), Q2.5 (D)
unnamed: J7.1, Q13.5 (D), Q14.5 (D)
unnamed: J10.1, Q8.5 (D)
unnamed: J8.1, J11.1, Q11.5 (D), Q12.5 (D)
unnamed: J9.1, J12.1, Q9.5 (D), Q10.5 (D)
unnamed: J13.A5 (CC1), R1.1
unnamed: J13.B5 (CC2), R2.2
unnamed: Q1.4 (G), Q2.4 (G), U3.7 (~OUT_A)
unnamed: Q3.4 (G), Q4.4 (G), U3.5 (~OUT_B)
unnamed: Q6.4 (G), U4.7 (~OUT_A)
unnamed: Q7.4 (G), U4.5 (~OUT_B)
unnamed: Q8.4 (G), U5.7 (~OUT_A)
unnamed: Q9.4 (G), Q10.4 (G), U5.5 (~OUT_B)
unnamed: Q11.4 (G), Q12.4 (G), U6.7 (~OUT_A)
unnamed: Q13.4 (G), Q14.4 (G), U6.5 (~OUT_B)
unnamed: R6.2, U1.20 (GPIO12/TOUCH12/ADC2_CH1/FSPICLK/FSPIIO6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)
unnamed: C4.1, U2.1 (BST)
unnamed: R3.2, R4.1, U2.3 (FB)
RST: C19.1, R5.2, SW1.1, U1.3 (EN)
USB_D+: J13.A6 (D+), J13.B6 (D+), U1.14 (GPIO20/U1CTS/ADC2_CH9/CLK_OUT1/USB_D+)
USB_D-: J13.A7 (D-), J13.B7 (D-), U1.13 (GPIO19/U1RTS/ADC2_CH8/CLK_OUT2/USB_D-)
VBUS: D2.2 (A), J13.A4 (VBUS), J13.A9 (VBUS), J13.B4 (VBUS), J13.B9 (VBUS)
VIN: C2.1, C3.1, C6.1, C8.1, C9.1, C10.1, C11.1, C12.1, C13.1, C14.1, C15.1, D2.1 (K), J1.2, J2.2, J3.2, J4.2, J5.2, J6.2, J7.2, J8.2, J9.2, J10.2, J11.2, J12.2, U2.4 (EN), U2.5 (VIN), U3.6 (V+), U4.6 (V+), U5.6 (V+), U6.6 (V+)

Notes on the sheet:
Enable bootloader/DFU
XT90
MCU reset
XT60

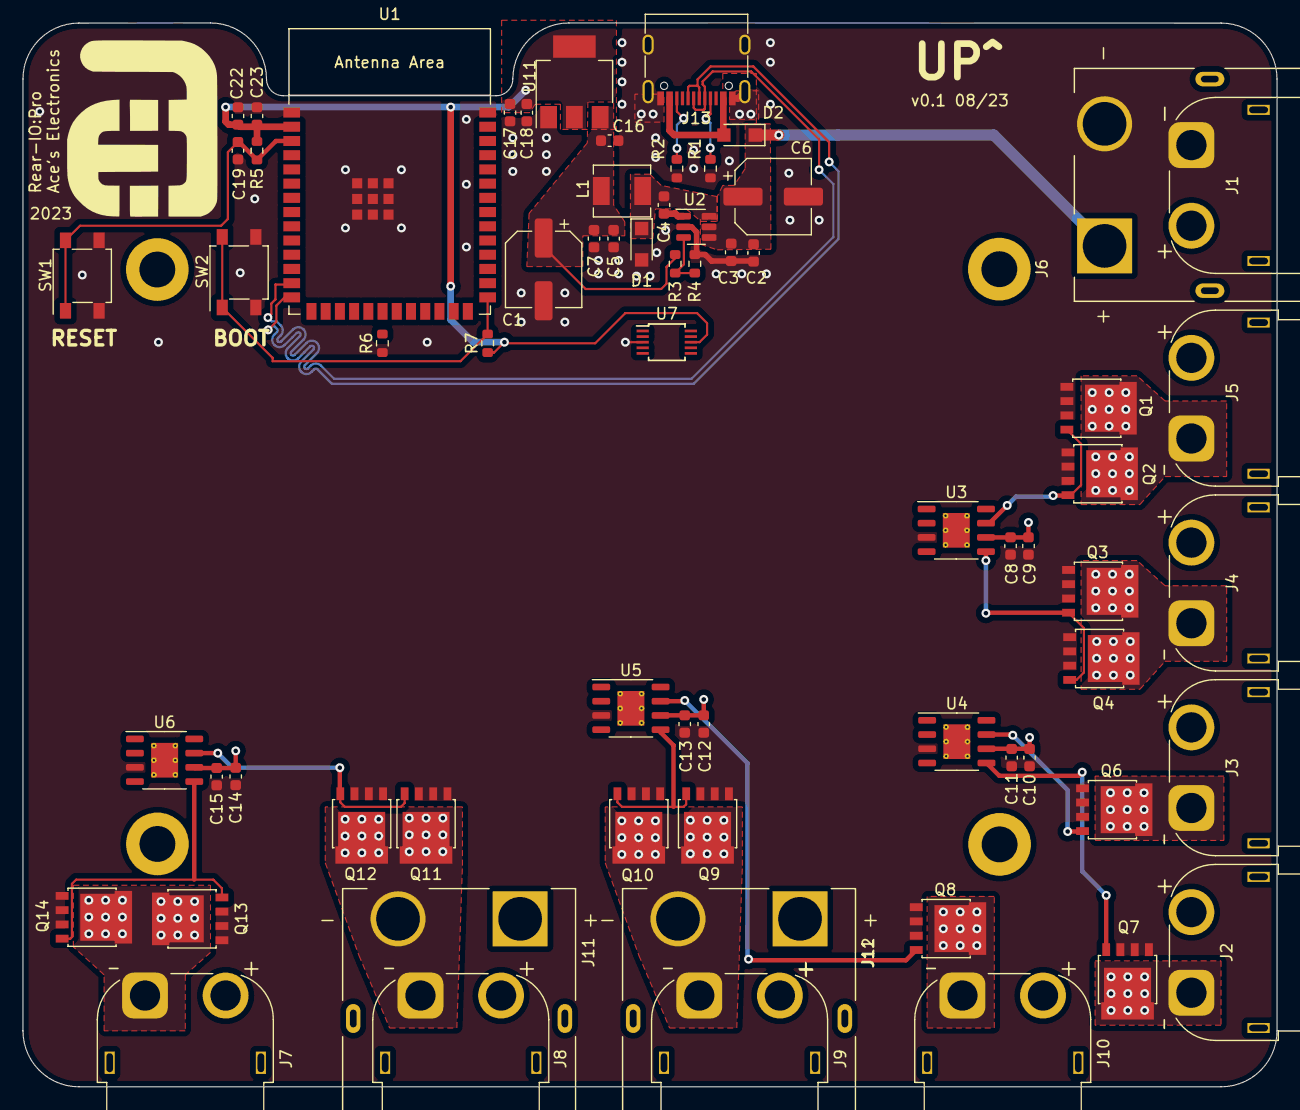
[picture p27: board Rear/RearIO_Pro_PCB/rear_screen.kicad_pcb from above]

Board: 4 copper layers, 112.0 x 95.0 mm, 71 parts (0 on the bottom side), 31 nets.

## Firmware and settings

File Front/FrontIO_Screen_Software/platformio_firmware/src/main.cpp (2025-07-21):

// FRONT IO Basic

#define TOUCH_MODULES_CST_SELF
#include <Arduino.h>
#include <driver/adc.h>
#include <nvs_flash.h>
#include <CircularBuffer.h>
#include "ui.h"
#include <Arduino_GFX_Library.h>
#include <TouchLib.h>
#include <esp_now.h>
#include <WiFi.h>
#include <lvgl.h>

#include "pin_config.h"

// GPIO definitions
const int vin = 14;
const int OP1 = 10; // outputs
const int OP2 = 11;
const int OP3 = 12;

const int OFF = 1;
const int ON = 0;

int rawValue = 0;
float lastReading;

int loopCounter;

const float r1 = 82000.0f; // R1 in ohm, 82k
const float r2 = 16000.0f; // R2 in ohm, 16k
float vRefScale = (3.3f / 4096.0f) * ((r1 + r2) / r2);
const int numReadings = 100;
int readings[numReadings];
int readIndex = 0;
long total = 0;

unsigned long newtime = 0;

CircularBuffer<float, 250> buffer;

// REPLACE WITH THE MAC Address of your receiver 
uint8_t broadcastAddress[] = {0xFF, 0xFF, 0xFF, 0xFF, 0xFF, 0xFF};

// Variable to store if sending data was successful
String success;

bool priorityMessage = 1;

typedef struct struct_message_priority {
  int messageID = 255;
} struct_message_priority;

//Must match the receiver structure
typedef struct struct_message_rear0 { // Rear hardware message
  int messageID = 0; // sets the message ID
  bool dataChanged = 0; // stores whether or not the data in the struct has changed
  int rearIO1 = -1; // rear: basic/pro IO1
  String rearIO1Name = "OP1";
  int rearIO2 = -1; // rear: basic/pro IO2
  String rearIO2Name = "OP2";
  int rearIO3 = -1; // rear: basic/pro IO3
  String rearIO3Name = "OP3";
  int rearIO4 = -1; // rear: basic/pro IO4
  String rearIO4Name = "N/A";
  int rearIO5 = -1; // rear: pro IO5
  String rearIO5Name = "-1";
  int rearIO6 = -1; // rear: pro IO6
  String rearIO6Name = "-1";
  int rearIO7 = -1; // rear: pro IO7
  String rearIO7Name = "-1";
  int rearIO8 = -1; // rear: pro IO8
  String rearIO8Name = "-1";
  int rearIO9 = -1; // rear: pro IO9
  String rearIO9Name = "-1";
  int rearIO10 = -1; // rear: pro IO10
  String rearIO10Name = "-1";
  
  String rearDeviceState = "WAIT!";
} struct_message_rear0;

typedef struct struct_message_aux0 { // Aux hardware message
  int messageID = 1;
  bool dataChanged = 0; // stores whether or not the data in the struct has changed
  String auxIO10Name = "-1";;
  int auxIO11 = -1; // aux: IO11
  String auxIO11Name = "-1";
  int auxIO12 = -1; // aux: IO12
  String auxIO12Name = "-1";
  int auxIO13 = -1; // aux: IO13
  String auxIO13Name = "-1";
  int auxIO14 = -1; // aux: IO14
  String auxIO14Name = "-1";
  int auxIO15 = -1; // aux: IO15
  String auxIO15Name = "-1";
  int auxIO16 = -1; // aux: IO16
  String auxIO16Name = "-1";
  int auxIO17 = -1; // aux: IO17
  String auxIO17Name = "-1";
  int auxIO18 = -1; // aux: IO18
  String auxIO18Name = "-1";
  int auxIO19 = -1; // aux: IO19
  String auxIO19Name = "-1";
  int auxIO20 = -1; // aux: IO20
  String auxIO20Name = "-1";

  String auxDeviceState = "WAIT!";
} struct_message_aux0;

typedef struct struct_message_front0 { // Front hardware message
  int messageID = 2;
  bool dataChanged = 0; // stores whether or not the data in the struct has changed
  int frontIO21 = -1; // front: basic/pro IO1
  String frontIO21Name = "-1";
  int frontIO22 = -1; // front: basic/pro IO2
  String frontIO22Name = "-1";
  int frontIO23 = -1; // front: basic/pro IO3
  String frontIO23Name = "-1";
  int frontIO24 = -1; // front: basic/pro IO4
  String frontIO24Name = "-1";
  int frontIO25 = -1; // front: pro IO5
  String frontIO25Name = "-1";
  int frontIO26 = -1; // front: pro IO6
  String frontIO26Name = "-1";
  int frontIO27 = -1; // front: pro IO7
  String frontIO28Name = "-1";
  int frontIO28 = -1; // front: pro IO8
  String frontIO29Name = "-1";
  int frontIO29 = -1; // front: pro IO9
  String frontIO30Name = "-1";
  int frontIO30 = -1; // front: pro IO10

  String frontDeviceState = "WAIT!";
} struct_message_front0;

typedef struct struct_message_voltage0 { // Voltage message
  int messageID = 3;
  bool dataChanged = 0; // stores whether or not the data in the struct has changed
  float frontMainBatt1V = -1;
  float frontAuxBatt1V = -1;
  float rearMainBatt1V = -1;
  float rearAuxBatt1V = -1;
  float frontMainBatt1I = -1;
  float frontAuxBatt1I = -1;
  float rearMainBatt1I = -1;
  float rearAuxBatt1I = -1; 
} struct_message_voltage0;

struct_message_priority priorityMessageStruct;

// Create a struct_message called localReadings to hold sensor readings
struct_message_rear0 localRear0Struct;
struct_message_aux0 localAux0Struct;
struct_message_front0 localFront0Struct;
struct_message_voltage0 localVoltage0Struct;

// Create a struct_message to hold incoming sensor readings
struct_message_rear0 remoteRear0Struct;
struct_message_aux0 remoteAux0Struct;
struct_message_front0 remoteFront0Struct;
struct_message_voltage0 remoteVoltage0Struct;

esp_now_peer_info_t peerInfo;

void sendMessage ()
{
  // create the data
  //localReadings0StructStruct.incomingio1Name[0] = 'Test';

  if (priorityMessage)
  {
    // Send message via ESP-NOW
    esp_err_t result0 = esp_now_send(broadcastAddress, (uint8_t *) &priorityMessageStruct, sizeof(priorityMessageStruct));
    if (result0 == ESP_OK) {
      Serial.println("Sent priority message with success");
    }
    else {
      Serial.println("Error sending the data");
    }
    priorityMessage = 0;
  }
  else
  {
    // Send message via ESP-NOW
    esp_err_t result0 = esp_now_send(broadcastAddress, (uint8_t *) &localRear0Struct, sizeof(localRear0Struct));
    if (result0 == ESP_OK) {
      Serial.println("Sent message 0 with success");
    }
    else {
      Serial.println("Error sending the data");
    }
    delay(200);
    esp_err_t result1 = esp_now_send(broadcastAddress, (uint8_t *) &localVoltage0Struct, sizeof(localVoltage0Struct));
    if (result1 == ESP_OK) {
      Serial.println("Sent message 1 with success");
    }
    else {
      Serial.println("Error sending the data");
    }
  }
}

// Callback when data is sent
void OnDataSent(const uint8_t *mac_addr, esp_now_send_status_t status) {
  Serial.print("\r\nLast Packet Send Status:\t");
  Serial.println(status == ESP_NOW_SEND_SUCCESS ? "Delivery Success" : "Delivery Fail");
  if (status ==0){
    success = "Delivery Success :)";
  }
  else{
    success = "Delivery Fail :(";
  }
}

void checkData()
{
  char rearAuxBatt1VChars[8];
  dtostrf(localVoltage0Struct.rearAuxBatt1V,6,2,rearAuxBatt1VChars);
  strcat(rearAuxBatt1VChars,"V");
  lv_label_set_text(ui_auxBattVoltageLabel, rearAuxBatt1VChars);
  if (localVoltage0Struct.rearAuxBatt1V < 11)
  {
    lv_label_set_text(ui_auxBattPercentageLabel, "FLAT!");
    lv_arc_set_value(ui_auxBattVoltageArc, 5);
    lv_obj_set_style_arc_color(ui_auxBattVoltageArc, lv_color_hex(0xFF0000), LV_PART_INDICATOR | LV_STATE_DEFAULT);
    lv_obj_set_style_bg_color(ui_auxBattVoltageArc, lv_color_hex(0xFF0000), LV_PART_KNOB | LV_STATE_DEFAULT);
    lv_obj_set_style_text_color(ui_auxBattPercentageLabel, lv_color_hex(0xFF0000), LV_PART_MAIN | LV_STATE_DEFAULT);
    lv_obj_set_style_text_color(ui_auxBattVoltageLabel, lv_color_hex(0xFF0000), LV_PART_MAIN | LV_STATE_DEFAULT);
  }
  else if (localVoltage0Struct.rearAuxBatt1V <= 12.0)
  {
    lv_label_set_text(ui_auxBattPercentageLabel, "9%");
    lv_arc_set_value(ui_auxBattVoltageArc, 9);
    lv_obj_set_style_arc_color(ui_auxBattVoltageArc, lv_color_hex(0xFF0000), LV_PART_INDICATOR | LV_STATE_DEFAULT);
    lv_obj_set_style_bg_color(ui_auxBattVoltageArc, lv_color_hex(0xFF0000), LV_PART_KNOB | LV_STATE_DEFAULT);
    lv_obj_set_style_text_color(ui_auxBattPercentageLabel, lv_color_hex(0xFF0000), LV_PART_MAIN | LV_STATE_DEFAULT);
    lv_obj_set_style_text_color(ui_auxBattVoltageLabel, lv_color_hex(0xFF0000), LV_PART_MAIN | LV_STATE_DEFAULT);
  }
  else if (localVoltage0Struct.rearAuxBatt1V <= 12.5)
  {
    lv_label_set_text(ui_auxBattPercentageLabel, "14%");
    lv_arc_set_value(ui_auxBattVoltageArc, 14);
    lv_obj_set_style_arc_color(ui_auxBattVoltageArc, lv_color_hex(0xFF0000), LV_PART_INDICATOR | LV_STATE_DEFAULT);
    lv_obj_set_style_bg_color(ui_auxBattVoltageArc, lv_color_hex(0xFF0000), LV_PART_KNOB | LV_STATE_DEFAULT);
    lv_obj_set_style_text_color(ui_auxBattPercentageLabel, lv_color_hex(0xFF0000), LV_PART_MAIN | LV_STATE_DEFAULT);
    lv_obj_set_style_text_color(ui_auxBattVoltageLabel, lv_color_hex(0xFF0000), LV_PART_MAIN | LV_STATE_DEFAULT);
  }
  else if (localVoltage0Struct.rearAuxBatt1V <= 12.8)
  {
    lv_label_set_text(ui_auxBattPercentageLabel, "17%");
    lv_arc_set_value(ui_auxBattVoltageArc, 17);
    lv_obj_set_style_arc_color(ui_auxBattVoltageArc, lv_color_hex(0xF06319), LV_PART_INDICATOR | LV_STATE_DEFAULT);
    lv_obj_set_style_bg_color(ui_auxBattVoltageArc, lv_color_hex(0xF06319), LV_PART_KNOB | LV_STATE_DEFAULT);
    lv_obj_set_style_text_color(ui_auxBattPercentageLabel, lv_color_hex(0xF06319), LV_PART_MAIN | LV_STATE_DEFAULT);
    lv_obj_set_style_text_color(ui_auxBattVoltageLabel, lv_color_hex(0xF06319), LV_PART_MAIN | LV_STATE_DEFAULT);
  }
  else if (localVoltage0Struct.rearAuxBatt1V <= 12.9)
  {
    lv_label_set_text(ui_auxBattPercentageLabel, "20%");
    lv_arc_set_value(ui_auxBattVoltageArc, 20);
    lv_obj_set_style_arc_color(ui_auxBattVoltageArc, lv_color_hex(0xE8B23B), LV_PART_INDICATOR | LV_STATE_DEFAULT);
    lv_obj_set_style_bg_color(ui_auxBattVoltageArc, lv_color_hex(0xE8B23B), LV_PART_KNOB | LV_STATE_DEFAULT);
    lv_obj_set_style_text_color(ui_auxBattPercentageLabel, lv_color_hex(0xE8B23B), LV_PART_MAIN | LV_STATE_DEFAULT);
    lv_obj_set_style_text_color(ui_auxBattVoltageLabel, lv_color_hex(0xE8B23B), LV_PART_MAIN | LV_STATE_DEFAULT);
  }
  else if (localVoltage0Struct.rearAuxBatt1V <= 13.0)
  {
    lv_label_set_text(ui_auxBattPercentageLabel, "30%");
    lv_arc_set_value(ui_auxBattVoltageArc, 30);
    lv_obj_set_style_arc_color(ui_auxBattVoltageArc, lv_color_hex(0xE8B23B), LV_PART_INDICATOR | LV_STATE_DEFAULT);
    lv_obj_set_style_bg_color(ui_auxBattVoltageArc, lv_color_hex(0xE8B23B), LV_PART_KNOB | LV_STATE_DEFAULT);
    lv_obj_set_style_text_color(ui_auxBattPercentageLabel, lv_color_hex(0xE8B23B), LV_PART_MAIN | LV_STATE_DEFAULT);
    lv_obj_set_style_text_color(ui_auxBattVoltageLabel, lv_color_hex(0xE8B23B), LV_PART_MAIN | LV_STATE_DEFAULT);
  }
  else if (localVoltage0Struct.rearAuxBatt1V <= 13.1)
  {
    lv_label_set_text(ui_auxBattPercentageLabel, "40%");
    lv_arc_set_value(ui_auxBattVoltageArc, 40);
    lv_obj_set_style_arc_color(ui_auxBattVoltageArc, lv_color_hex(0xE3ED00), LV_PART_INDICATOR | LV_STATE_DEFAULT);
    lv_obj_set_style_bg_color(ui_auxBattVoltageArc, lv_color_hex(0xE3ED00), LV_PART_KNOB | LV_STATE_DEFAULT);
    lv_obj_set_style_text_color(ui_auxBattPercentageLabel, lv_color_hex(0xE3ED00), LV_PART_MAIN | LV_STATE_DEFAULT);
    lv_obj_set_style_text_color(ui_auxBattVoltageLabel, lv_color_hex(0xE3ED00), LV_PART_MAIN | LV_STATE_DEFAULT);
  }
  else if (localVoltage0Struct.rearAuxBatt1V <= 13.15)
  {
    lv_label_set_text(ui_auxBattPercentageLabel, "70%");
    lv_arc_set_value(ui_auxBattVoltageArc, 70);
    lv_obj_set_style_arc_color(ui_auxBattVoltageArc, lv_color_hex(0x00FF00), LV_PART_INDICATOR | LV_STATE_DEFAULT);
    lv_obj_set_style_bg_color(ui_auxBattVoltageArc, lv_color_hex(0x00FF00), LV_PART_KNOB | LV_STATE_DEFAULT);
    lv_obj_set_style_text_color(ui_auxBattPercentageLabel, lv_color_hex(0x00FF00), LV_PART_MAIN | LV_STATE_DEFAULT);
    lv_obj_set_style_text_color(ui_auxBattVoltageLabel, lv_color_hex(0x00FF00), LV_PART_MAIN | LV_STATE_DEFAULT);
  }
  else if (localVoltage0Struct.rearAuxBatt1V <= 13.3)
  {
    lv_label_set_text(ui_auxBattPercentageLabel, "90%");
    lv_arc_set_value(ui_auxBattVoltageArc, 90);
    lv_obj_set_style_arc_color(ui_auxBattVoltageArc, lv_color_hex(0x00FF00), LV_PART_INDICATOR | LV_STATE_DEFAULT);
    lv_obj_set_style_bg_color(ui_auxBattVoltageArc, lv_color_hex(0x00FF00), LV_PART_KNOB | LV_STATE_DEFAULT);
    lv_obj_set_style_text_color(ui_auxBattPercentageLabel, lv_color_hex(0x00FF00), LV_PART_MAIN | LV_STATE_DEFAULT);
    lv_obj_set_style_text_color(ui_auxBattVoltageLabel, lv_color_hex(0x00FF00), LV_PART_MAIN | LV_STATE_DEFAULT);
  }
  else if (localVoltage0Struct.rearAuxBatt1V <= 13.4)
  {
    lv_label_set_text(ui_auxBattPercentageLabel, "99%");
    lv_arc_set_value(ui_auxBattVoltageArc, 99);
    lv_obj_set_style_arc_color(ui_auxBattVoltageArc, lv_color_hex(0x00FF00), LV_PART_INDICATOR | LV_STATE_DEFAULT);
    lv_obj_set_style_bg_color(ui_auxBattVoltageArc, lv_color_hex(0x00FF00), LV_PART_KNOB | LV_STATE_DEFAULT);
    lv_obj_set_style_text_color(ui_auxBattPercentageLabel, lv_color_hex(0x00FF00), LV_PART_MAIN | LV_STATE_DEFAULT);
    lv_obj_set_style_text_color(ui_auxBattVoltageLabel, lv_color_hex(0x00FF00), LV_PART_MAIN | LV_STATE_DEFAULT);
  }
  else if (localVoltage0Struct.rearAuxBatt1V <= 13.55)
  {
    lv_label_set_text(ui_auxBattPercentageLabel, "100%");
    lv_arc_set_value(ui_auxBattVoltageArc, 100);
    lv_obj_set_style_arc_color(ui_auxBattVoltageArc, lv_color_hex(0x00FF00), LV_PART_INDICATOR | LV_STATE_DEFAULT);
    lv_obj_set_style_bg_color(ui_auxBattVoltageArc, lv_color_hex(0x00FF00), LV_PART_KNOB | LV_STATE_DEFAULT);
    lv_obj_set_style_text_color(ui_auxBattPercentageLabel, lv_color_hex(0x00FF00), LV_PART_MAIN | LV_STATE_DEFAULT);
    lv_obj_set_style_text_color(ui_auxBattVoltageLabel, lv_color_hex(0x00FF00), LV_PART_MAIN | LV_STATE_DEFAULT);
  }
  else if (localVoltage0Struct.rearAuxBatt1V <= 16.00)
  {
    lv_label_set_text(ui_auxBattPercentageLabel, "100%");
    lv_arc_set_value(ui_auxBattVoltageArc, 100);
    lv_obj_set_style_arc_color(ui_auxBattVoltageArc, lv_color_hex(0x00FF00), LV_PART_INDICATOR | LV_STATE_DEFAULT);
    lv_obj_set_style_bg_color(ui_auxBattVoltageArc, lv_color_hex(0x00FF00), LV_PART_KNOB | LV_STATE_DEFAULT);
    lv_obj_set_style_text_color(ui_auxBattPercentageLabel, lv_color_hex(0x00FF00), LV_PART_MAIN | LV_STATE_DEFAULT);
    lv_obj_set_style_text_color(ui_auxBattVoltageLabel, lv_color_hex(0x00FF00), LV_PART_MAIN | LV_STATE_DEFAULT);
  }
  // else // ToDo: work out why this was being triggered
  // {
  //   lv_label_set_text(ui_auxBattPercentageLabel, "V HIGH!");
  //   lv_arc_set_value(ui_auxBattVoltageArc, 100);
  //   lv_obj_set_style_arc_color(ui_auxBattVoltageArc, lv_color_hex(0x00FF00), LV_PART_INDICATOR | LV_STATE_DEFAULT);
  //   lv_obj_set_style_bg_color(ui_auxBattVoltageArc, lv_color_hex(0x00FF00), LV_PART_KNOB | LV_STATE_DEFAULT);
  //   lv_obj_set_style_text_color(ui_auxBattPercentageLabel, lv_color_hex(0x00FF00), LV_PART_MAIN | LV_STATE_DEFAULT);
  //   lv_obj_set_style_text_color(ui_auxBattVoltageLabel, lv_color_hex(0x00FF00), LV_PART_MAIN | LV_STATE_DEFAULT);
  // }
  
  
  if (localVoltage0Struct.rearAuxBatt1V < 10.00) // ToDO: double check this
  {
    lv_obj_set_style_text_color(ui_hp1Label, lv_color_hex(0xFF0000), LV_PART_MAIN | LV_STATE_DEFAULT);
    lv_obj_set_style_text_color(ui_hp2Label, lv_color_hex(0xFF0000), LV_PART_MAIN | LV_STATE_DEFAULT);
    lv_obj_set_style_text_color(ui_lp1Label, lv_color_hex(0xFF0000), LV_PART_MAIN | LV_STATE_DEFAULT);
  }
  else 
  {
    if (localRear0Struct.rearIO1 == ON)
    {
      lv_obj_set_style_text_color(ui_hp1Label, lv_color_hex(0x00FF00), LV_PART_MAIN | LV_STATE_DEFAULT);
      lv_obj_add_state(ui_io1, LV_STATE_CHECKED);
    }
    else
    {
      lv_obj_set_style_text_color(ui_hp1Label, lv_color_hex(0x808080), LV_PART_MAIN | LV_STATE_DEFAULT);
      lv_obj_clear_state(ui_io1, LV_STATE_CHECKED);
    }
      if (localRear0Struct.rearIO2 == ON)
    {
      lv_obj_set_style_text_color(ui_hp2Label, lv_color_hex(0x00FF00), LV_PART_MAIN | LV_STATE_DEFAULT);
      lv_obj_add_state(ui_io2, LV_STATE_CHECKED);
    }
    else
    {
      lv_obj_set_style_text_color(ui_hp2Label, lv_color_hex(0x808080), LV_PART_MAIN | LV_STATE_DEFAULT);
      lv_obj_clear_state(ui_io2, LV_STATE_CHECKED);
    }
      if (localRear0Struct.rearIO3 == ON)
    {
      lv_obj_set_style_text_color(ui_lp1Label, lv_color_hex(0x00FF00), LV_PART_MAIN | LV_STATE_DEFAULT);
      lv_obj_add_state(ui_io3, LV_STATE_CHECKED);
    }
    else
    {
      lv_obj_set_style_text_color(ui_lp1Label, lv_color_hex(0x808080), LV_PART_MAIN | LV_STATE_DEFAULT);
      lv_obj_clear_state(ui_io3, LV_STATE_CHECKED);
    }
  }
}
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
void loop()
{
  lv_timer_handler(); /* let the GUI do its work */
  
  if (loopCounter % 2500 == 0) // ~60 secs
  {
    Serial.println("Sending sync message!");
    sendMessage();
    loopCounter = 0;
  }
  loopCounter++;
  delay(5);
}

//------------------------------------------------------------------------

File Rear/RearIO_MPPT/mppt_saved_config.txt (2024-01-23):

BatType: 0
BatCap: 50
TempComp: -3
OVCutOff: 15.60
ChargLmt: 14.60
OVRcv: 14.70
EquilV: 14.60
RaisV: 14.20
FloCharg: 13.60
RaisRcv: 13.30
LVRcv: 12.00
WarnRcv: 12.20
LVWarn: 11.80
LVCutOff: 11.20
DischaLmt: 11.00
RatedLv: 0
EquilDur: 0
RaisDur: 30
BatDisch: 30
BatCharg: 100
ChargMode: 0

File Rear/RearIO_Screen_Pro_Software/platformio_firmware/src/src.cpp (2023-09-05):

#define LGFX_USE_V1

#include <Arduino.h>
#include <LovyanGFX.hpp>
#include "lvgl.h"
#include "ui.h"

class LGFX : public lgfx::LGFX_Device
{

lgfx::Panel_ST7796      _panel_instance;
lgfx::Bus_Parallel8 _bus_instance;   // 8ビットパラレルバスのインスタンス (ESP32のみ)
lgfx::Light_PWM     _light_instance;
lgfx::Touch_FT5x06           _touch_instance; // FT5206, FT5306, FT5406, FT6206, FT6236, FT6336, FT6436

public:
  LGFX(void)
  {
    { // バス制御の設定を行います。
      auto cfg = _bus_instance.config();    // バス設定用の構造体を取得します。
// 8ビットパラレルバスの設定
      //cfg.i2s_port = I2S_NUM_0;     // 使用するI2Sポートを選択 (I2S_NUM_0 or I2S_NUM_1) (ESP32のI2S LCDモードを使用します)
      cfg.freq_write = 20000000;    // 送信クロック (最大20MHz, 80MHzを整数で割った値に丸められます)
      cfg.pin_wr =  47;              // WR を接続しているピン番号
      cfg.pin_rd =  -1;              // RD を接続しているピン番号
      cfg.pin_rs = 0;              // RS(D/C)を接続しているピン番号
      cfg.pin_d0 = 9;              // D0を接続しているピン番号
      cfg.pin_d1 = 46;              // D1を接続しているピン番号
      cfg.pin_d2 = 3;              // D2を接続しているピン番号
      cfg.pin_d3 = 8;              // D3を接続しているピン番号
      cfg.pin_d4 = 18;              // D4を接続しているピン番号
      cfg.pin_d5 = 17;              // D5を接続しているピン番号
      cfg.pin_d6 = 16;              // D6を接続しているピン番号
      cfg.pin_d7 = 15;              // D7を接続しているピン番号
      _bus_instance.config(cfg);    // 設定値をバスに反映します。
      _panel_instance.setBus(&_bus_instance);      // バスをパネルにセットします。
    }

    { // 表示パネル制御の設定を行います。
      auto cfg = _panel_instance.config();    // 表示パネル設定用の構造体を取得します。

      cfg.pin_cs           =    -1;  // CSが接続されているピン番号   (-1 = disable)
      cfg.pin_rst          =    4;  // RSTが接続されているピン番号  (-1 = disable)
      cfg.pin_busy         =    -1;  // BUSYが接続されているピン番号 (-1 = disable)

      // ※ 以下の設定値はパネル毎に一般的な初期値が設定されていますので、不明な項目はコメントアウトして試してみてください。

      cfg.panel_width      =   320;  // 実際に表示可能な幅
      cfg.panel_height     =   480;  // 実際に表示可能な高さ
      cfg.offset_x         =     0;  // パネルのX方向オフセット量
      cfg.offset_y         =     0;  // パネルのY方向オフセット量
      cfg.offset_rotation  =     0;  // 回転方向の値のオフセット 0~7 (4~7は上下反転)
      cfg.dummy_read_pixel =     8;  // ピクセル読出し前のダミーリードのビット数
      cfg.dummy_read_bits  =     1;  // ピクセル以外のデータ読出し前のダミーリードのビット数
      cfg.readable         =  true;  // データ読出しが可能な場合 trueに設定
      cfg.invert           = true;  // パネルの明暗が反転してしまう場合 trueに設定
      cfg.rgb_order        = false;  // パネルの赤と青が入れ替わってしまう場合 trueに設定
      cfg.dlen_16bit       = false;  // 16bitパラレルやSPIでデータ長を16bit単位で送信するパネルの場合 trueに設定
      cfg.bus_shared       =  true;  // SDカードとバスを共有している場合 trueに設定(drawJpgFile等でバス制御を行います)

// 以下はST7735やILI9163のようにピクセル数が可変のドライバで表示がずれる場合にのみ設定してください。
//    cfg.memory_width     =   240;  // ドライバICがサポートしている最大の幅
//    cfg.memory_height    =   320;  // ドライバICがサポートしている最大の高さ

      _panel_instance.config(cfg);
    }

//*
    { // バックライト制御の設定を行います。（必要なければ削除）
      auto cfg = _light_instance.config();    // バックライト設定用の構造体を取得します。

      cfg.pin_bl = 45;              // バックライトが接続されているピン番号
      cfg.invert = false;           // バックライトの輝度を反転させる場合 true
      cfg.freq   = 44100;           // バックライトのPWM周波数
      cfg.pwm_channel = 7;          // 使用するPWMのチャンネル番号

      _light_instance.config(cfg);
      _panel_instance.setLight(&_light_instance);  // バックライトをパネルにセットします。
    }
//*/

//*
    { // タッチスクリーン制御の設定を行います。（必要なければ削除）
      auto cfg = _touch_instance.config();

      cfg.x_min      = 0;    // タッチスクリーンから得られる最小のX値(生の値)
      cfg.x_max      = 319;  // タッチスクリーンから得られる最大のX値(生の値)
      cfg.y_min      = 0;    // タッチスクリーンから得られる最小のY値(生の値)
      cfg.y_max      = 479;  // タッチスクリーンから得られる最大のY値(生の値)
      cfg.pin_int    = 7;   // INTが接続されているピン番号
      cfg.bus_shared = true; // 画面と共通のバスを使用している場合 trueを設定
      cfg.offset_rotation = 0;// 表示とタッチの向きのが一致しない場合の調整 0~7の値で設定
// I2C接続の場合
      cfg.i2c_port = 1;      // 使用するI2Cを選択 (0 or 1)
      cfg.i2c_addr = 0x38;   // I2Cデバイスアドレス番号
      cfg.pin_sda  = 6;     // SDAが接続されているピン番号
      cfg.pin_scl  = 5;     // SCLが接続されているピン番号
      cfg.freq = 400000;     // I2Cクロックを設定

      _touch_instance.config(cfg);
      _panel_instance.setTouch(&_touch_instance);  // タッチスクリーンをパネルにセットします。
    }
//*/
    setPanel(&_panel_instance); // 使用するパネルをセットします。
  }
};

// 準備したクラスのインスタンスを作成します。

LGFX tft;

#define screenWidth 480
#define screenHeight 320

static lv_disp_draw_buf_t draw_buf;
static lv_color_t buf[screenWidth * 10];

void my_disp_flush(lv_disp_drv_t *disp, const lv_area_t *area, lv_color_t *color_p) {
  uint32_t w = (area->x2 - area->x1 + 1);
  uint32_t h = (area->y2 - area->y1 + 1);
  tft.startWrite();
  tft.setAddrWindow(area->x1, area->y1, w, h);
  tft.writePixels((lgfx::rgb565_t *)&color_p->full, w * h);
  tft.endWrite();
  lv_disp_flush_ready(disp);
}

void my_touch_read(lv_indev_drv_t *indev_driver, lv_indev_data_t *data) {
    uint16_t touchX, touchY;
    bool touched = tft.getTouch(&touchX, &touchY);
    if (!touched) { data->state = LV_INDEV_STATE_REL; }
    else {
      data->state = LV_INDEV_STATE_PR;
      data->point.x = touchX;
      data->point.y = touchY;
    }
}


static lv_style_t label_style;
static lv_obj_t *headerLabel;
static lv_obj_t * label;

void set_screen_brightness(lv_event_t * e)
{
    lv_obj_t * slider = lv_event_get_target(e);

    int brightness = lv_slider_get_value(slider);
	  if (brightness < 10) brightness = 10;
    tft.setBrightness(brightness * 2.55);
}

void setup() {
  Serial.begin(115200);

  tft.begin();
  tft.setRotation(1); // 3 = upside down
  tft.setBrightness(255); // ToDo: make this an NVRAM setting and read it in on boot

  lv_init();
  lv_disp_draw_buf_init(&draw_buf, buf, NULL, screenWidth * 10);
  static lv_disp_drv_t disp_drv;
  lv_disp_drv_init(&disp_drv);
  disp_drv.hor_res = screenWidth;
  disp_drv.ver_res = screenHeight;
  disp_drv.flush_cb = my_disp_flush;
  disp_drv.draw_buf = &draw_buf;
  lv_disp_drv_register(&disp_drv);
  static lv_indev_drv_t indev_drv;
  lv_indev_drv_init(&indev_drv);
  indev_drv.type = LV_INDEV_TYPE_POINTER;
  indev_drv.read_cb = my_touch_read;
  lv_indev_drv_register(&indev_drv);
  
  ui_init();
}


void loop() {
  lv_timer_handler();
  delay(5);
}

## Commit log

2023-08-19 update, basic board complete
    [BOM-rear_screen.csv, LCSC_Bom_Exported_2023-08-19.csv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]
2023-08-19 Sent to JLCPCB as Rev0
    [BOM-rear_screen.csv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]
2023-08-20 changing layout and updating ReadME
    [BOM-rear_screen.csv, LCSC_Bom_Exported_2023-08-19.csv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]
2023-08-20 added screen mount
2023-09-06 Dynamic battery state updates
2023-09-07 small routing and layout changes, removed USB
    [rear_screen.kicad_pcb, rear_screen.kicad_sch]
2023-09-07 voltage state changes
2023-09-07 routing and layout changes
    [rear_screen.kicad_pcb, rear_screen.kicad_sch]
2023-09-08 v0.2 submitted to JLCPCB
    [BOM-rear_screen.csv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]
2024-05-28 Started work on v0.3 software
    [BOM-rear_screen.csv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]
2024-05-31 Final UI changes
    [rear_screen.kicad_sch]
2025-07-21 save point before modifying front UI
    [BOM-ae_emblem_led_pcb.csv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]
